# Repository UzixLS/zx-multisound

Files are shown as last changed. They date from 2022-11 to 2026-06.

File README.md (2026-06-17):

## ZX-MultiSound
Sound card for ZX Spectrum (NemoBus).

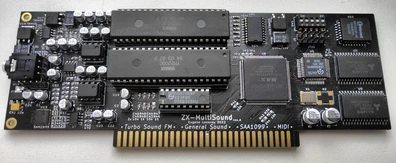
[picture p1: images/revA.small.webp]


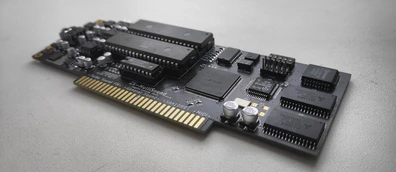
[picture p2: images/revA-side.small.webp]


### Tech specs
* TurboSound FM (2xYM2203)
* General Sound (16MHz, 1024Kb of RAM)
* SAA1099 (use port #FF/#1FF to access SAA chip, write #F7/#FF to #FFFD port to enable/disable SAA)
* SounDrive (ports #0F, #1F, #4F, #5F)
* MIDI synthesizer (controlled via YM(AY) chip - compatible with ZX Spectrum 128K / ZXUNO)
* Low profile PCB: 170x64mm
* 5V and 12V power required
* 4x 1-bit digital DACs for GS and SounDrive

### Changelog & current status
* Rev.A - first release. Please note the [errata](pcb/rev.A/ERRATA.txt);
* Rev.A1 - fixed known rev.A issues. Please note the [errata](pcb/rev.A1/ERRATA.txt).
* Rev.A2:
    * Fixed Z80 clocking - added buffer;
    * Fixed 3.5mm jack footprint swapped left-right channels;
    * Fixed misplaced R20 and R34 labels on silkscreen;
    * 74LVC1G125DB replaced by 74AHCT1G125DB;
    * C3,C5,C17,C18 slightly moved left;
    * Added ledge on edge connector;
    * Improved SAM2695 footprint for hand soldering.
Sound card has been tested only with ZX Evolution. You can use it with another computer at your own risk.

### Related projects
* Turbo Sound FM - [link](http://www.nedopc.com/TURBOSOUND/ts-fm.php)
* ZXM-SoundCard - [link](http://micklab.ru/My%20Soundcard/ZXMSoundCard.htm)
* ZXM-GeneralSound - [link](http://micklab.ru/My%20Soundcard/ZXMGeneralSound.htm)
* NeoGS - [link](http://www.nedopc.com/gs/ngs.php)

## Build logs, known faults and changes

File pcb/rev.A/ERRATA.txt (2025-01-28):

1. Missing MREQ signal. You should wire MREQ from edge connector to TP1
2. R2, R33 - 10K
3. R6, R12, R30, R31 - 47k

UPD. 2023-08-21:
4. R20 and R34 labels on silkscreen are misplaced
5. Incorrect 3.5mm jack footprint - left-right signals are swapped

UPD. 2025-01-28:
6. U21 should be 74AHCT1G125DB
7. Missing Z80 clock buffering. CPLD produce only up to 3.3V clock, while Z80 require 5V amplitude, and that may lead to unstable GS work. It's possible to use U14 for clock buffering.

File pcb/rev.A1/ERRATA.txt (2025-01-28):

1. R20 and R34 lables on silkscreen are misplaced
2. Incorrect 3.5mm jack footprint - left-right signals are swapped

UPD. 2025-01-28:
3. U21 should be 74AHCT1G125DB
4. Missing Z80 clock buffering. CPLD produce only up to 3.3V clock, while Z80 require 5V amplitude, and that may lead to unstable GS work. It's possible to use U14 for clock buffering.

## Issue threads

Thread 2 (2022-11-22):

Даешь больше дырок!

NEO-SPECTRUMAN, 2022-11-22:
Нету отверстий для прикручивания радиаторов к 2203

UzixLS, 2022-11-22:
Так надо водяную систему охлаждения использовать :)

NEO-SPECTRUMAN, 2022-11-22:
можно конечно преклеивать
но мне такая идея не нравитсо
а тотом придетсо отклеивать...

NEO-SPECTRUMAN, 2022-11-22:
кстате в данном случае может можно 2 штуки между 2203-ми
на термопасте хорошо ляжет на 2 опоры

UzixLS, 2022-11-22:
а зачем отклеивать если чип всё равно горячий?

NEO-SPECTRUMAN, 2022-11-22:
отклеивать от сгоревшего чтобы приклеить к новому :rofl:

NEO-SPECTRUMAN, 2022-11-22:
ну свидетели ложения чипов в вазочку на полочке не одобряют приклеивание чипов

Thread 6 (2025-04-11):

2203 busy latency and missed busy after reg select

NS-Clone, 2025-04-11:
вощем такие дела
записали на мультисаунде сигнал busy с 2203
и как оказалось
busy вообще не ОТСУТСТВУЕТ после выбора регистра
(собственно тоже самое и на 2612 и 3438)
когда он нужен

а busy мало того что одинаковый для всех регистров 90t (даже для SSG части)
так еще и после записи данных появляется с задержкой

график вероятности ловли сигнала busy после out (с),r
(не обращаем на зашумленность единицы на 28 мгц это изза недостаточного количества выборок и простоты визуализации графика)
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

и если на 3.5 Мгц все это проскакивается изза общей величины кода
то на 28МГц 10 тактов отсутствия busy это 80 такта z80...

и вот эта схема просто физически не работает уже даже на 14МГц
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

изза большого разброса частот проца
делать софтварную задержку не очень эффективно
хотя можно делать динамическую подстраиваемую под частоту проца

переключать на 3.5 МГц на время плеера
...успешно нельзя сейчас в недооси
ибо там какойто умник решил что частота должно щелкатсо раз в фрейм...

ну и конечно старые софты никто уже непофискит
да и новые еще будут выходить с игнором этой фичи...

как хардварное решение видитсо имитация сигнала busy средствами самой карты

в 2-х мануалах на более старшые OPN-ы
даютсо нужные времянки неготовности чипа

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

но это 6 канальные чипы на двойной частоте
и для нас эти времянки могут отличаются
(например фисировання длина busy на 2612 и 3438 192 такта против 90 у нас)
и нужные задержки видимо нужно подбирать методом научного тыка

так же на форуме сежистов упоминаетсо что якобы эти цифры похожи на правду
кроме регистра 0x28
которому надо 116 тактов
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

собственно мы немного тыкали софтварные задержки
и возможно этот 0x28 отвалилсо первым :)

NS-Clone, 2025-04-12:
рав данные того что выше с Koegon+Multisound
28, 14, 3.5 МГц (растянуто по коэфициенту турбы

в коегоне видимо 28МГц не 100%
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

еще подвезли записи с EVO+ZXM-Soundcard Extreme
14, 7, 3.5 МГц (растянуто по коэфициенту турбы

и тут мы видим вообще пропуски busy через такт в конце сигнала! на 14МГц
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

тк этот результат насторожил
добавил busy и на выбор регистра и на запись даты в унриал
и записал на частотах 28, 14, 7, 3.5 (в моем унриале турба щелкаетсо в отличииот ваших)

и там записался и busy после выбора регистра (которого нет на реале)
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

и busy после записи данных
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

обращаем внимание на отсутствие размытости краев

так что пока предполагаем что мой тест рабочий

UzixLS, 2025-04-19:
Я правильно понял что это "фича" самого 2203 и проявляется на всех картах с его использованием?

NS-Clone, 2025-04-19:
до
это фича походу всех opn-ов

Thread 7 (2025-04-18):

MIDI+Turbo

NS-Clone, 2025-04-18:
там много лгбт с этим биперным мидом в 100500 вариантах турбы

...а там жеш есть модифицированный ngs де стоит мп3декодер со встроенным мидом
можот и тут можно вынести (продублироваь) как то порты мида на сторону гс-а
(может даже сделать как то совместимо с тем нгс-ом)
и чтоб оно ужо само харваврно слало в sam2695 принимая по людски 1 байт
и отправляя последовательно уже само
может даже через порт Ay-ка (но самостоятельно без з80)
чтобы не менять плату

да и в саму прошивку гс-а можно было бы добавить режим пуляния данных в миду

UzixLS, 2025-04-19:
Вообще для миди в спектруме есть разные варианты подключения. Вот что, например, поддерживает Es.pectrum:
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
Вот только доки на всё это я хз где искать

NS-Clone, 2025-04-19:
> Вот только доки на всё это я хз где искать

да там в лохматые времена было много мидов...
вон у нас дажо скорпионовский мида был...

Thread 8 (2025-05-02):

Неработает GS на Коегоне

NS-Clone, 2025-05-02:
у трансмана из коробки незаводитсо ГС
(видимо на 3,5мгц тоже)
и судя по всему ужо 2-я карта подряд

тут я прицеплю цитату наверное от кое
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

хотя там у него еще проблема с ум-кой паралельна
может проблема и не в карте

UzixLS, 2025-05-03:
Какая ревизия платы? На A1 есть бага в GS части, на A2 поправлено: https://github.com/UzixLS/zx-multisound/blob/master/pcb/rev.A1/ERRATA.txt

Zorba2030, 2025-05-03:
ревизия А1. Сборка Tetroid'a. Но он проверяет перед отправкой на zx-evolution.
Какие варианты есть чтобы выяснить причину и починить, не окирпичив ее при этом?

UzixLS, 2025-05-03:
Тогда хз, гадать почему не работает можно очень долго, а Коегона (кстати, что это за клон? гугл не знает) у меня нету.

Zorba2030, 2025-05-03:
Это pentagon 2.666 le.
А что по поводу предположения, высказанного KoE о возможной причине несовместимости?

NS-Clone, 2025-05-03:
> а Коегона (кстати, что это за клон? гугл не знает) у меня нету.

в принципе коегона ниукого нету :rofl:
а про гуглу можно уже забывать...

UzixLS, 2025-05-03:
> А что по поводу предположения, высказанного KoE о возможной причине несовместимости?

Если под "неправильно формируется iorqge" имеется ввиду что в оригинальном ГС используются какие-то другие сигналы кроме m1 и шины адреса - то нет, в МС такого нет.

Closed 2025-05-04.

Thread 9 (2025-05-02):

Неправильный делитель на 2203 после сброса?

NS-Clone, 2025-05-02:
У трансмана на Коегоне (наверно 2.666ЛЕ) ВНЕЗАПНО перестал нормально играть AY
(типа играет на неправильной частоте)
хотя по началу он вроде играл
потом он ткнул другую такую карту
и там все тоже самое
(и на 3,5мгц вроде тоже не играет)

при этом судя по всему
после tsfm плееров которые инициализируют делитель
AY (SSG) потом играет нормально везде
(видимо фм часть тоже фурычит и так)

сам же 2203 по идеи должен сбрасывать делитель при сбросе

нет идей чего могло пойти не так?
типа "дребезга" сброса изза которого YM-ка неправильно сбрасываесто
или может пиковое потребление при старте большое а бп ужо не торт
этим можно было бы объяснить и нерабочесть ГС-а

UzixLS, 2025-05-03:
> сам же 2203 по идеи должен сбрасывать делитель при сбросе
Возможно, нет самого сигнала сброса либо он слишком короткий.

Zorba2030, 2025-05-03:
Всё-таки это оказался сигнал reset. При принудительной его активации всё начинает работать правильно.

NS-Clone, 2025-05-04:
до но интересно что оно жо работало с начала
тобешь это или "дребезг" усугубилсо
или блоку питания поплохело

Closed 2025-05-04.

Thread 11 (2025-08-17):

Clicks in TS/TSFM Mode

zxshock, 2025-08-17:
Noticed this during the demo loop for "Ball Quest" (https://files.scene.org/view/parties/2006/chaosconstructions06/game/ballques.zip)

If you look at the recordings there are noticeable clicks at 18.25 seconds, 20.5 seconds, 42.5 seconds and twice at 45.5 seconds (item pickups in first ingame demo). This also happens on Pentagon 1024SL 2.2
[ZX_Multisound-ZX_Evolution.mp3](https://github.com/user-attachments/files/21824429/ZX_Multisound-ZX_Evolution.mp3)

For comparision, this does not happen with a NedoPC TSFM (plugged into the AY socket, chips taken from my ZX Multisound to rule out defects)
[TSFM-ZX_Evolution.mp3](https://github.com/user-attachments/files/21824430/TSFM-ZX_Evolution.mp3)

Hardware:
ZX Multisound Revision A2, Firmware a696ecd (also happens with e952ec2)
TSFM (http://nedopc.com/TURBOSOUND/ts-fm.php, EPM7032 firmware from 29.05.2022)
ZX Evo Rev. C + dualConf (baseconf 21.09.2024 beta, AVR Boot 25.05.2019)

zxshock, 2025-08-20:
I'm confused (but then again I've never learned Verilog or Z80 debugging) ... and managed to get rid of the clicking in another way.

Doesn't seem to be related to bit3 (already wondered, as commenting out the whole SAA1099 section didn't help), but rather bit2?
Issue can also be fixed by commenting out lines 122 and 123, which of course disables FM. Still doesn't explain why checking for d3 to be 1 also fixed things - but at this point I'm just guessing

I've now made this change to the TSFM section, using SW1.5 for setting fm_ena and it seems to have fixed Ball Quest at the cost of disabling FM via the previously unused switch.

```
    else if (port_fffd && ioreq_wr && d[7:4] == 4'b1111 && fm_ena == 1'b1) begin
        ym_chip_sel <= d[0];
        ym_get_stat <= ~d[1];
        fm1_ena <= d[2]? 1'b0 : 1'bz;
        fm2_ena <= d[2]? 1'b0 : 1'bz;
    end
    else if (port_fffd && ioreq_wr && d[7:4] == 4'b1111 && fm_ena == 1'b0) begin
        ym_chip_sel <= d[0];
    end

```

Maybe this comes down to the different implementations of the FM enable in hardware? Open drain vs. 2 seperate signals (TSFM, TSFMPro, ZXM Soundcard)

UzixLS, 2025-08-21:
This should not be surprising. The clicks are not caused by the addressing itself, but by an unintentional change in the hardware configuration that is caused by the addressing.

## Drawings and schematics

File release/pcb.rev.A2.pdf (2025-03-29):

1 | 2 | 3 | 4 | 5 | 6 | 7 | 8 | 9 | 10

A

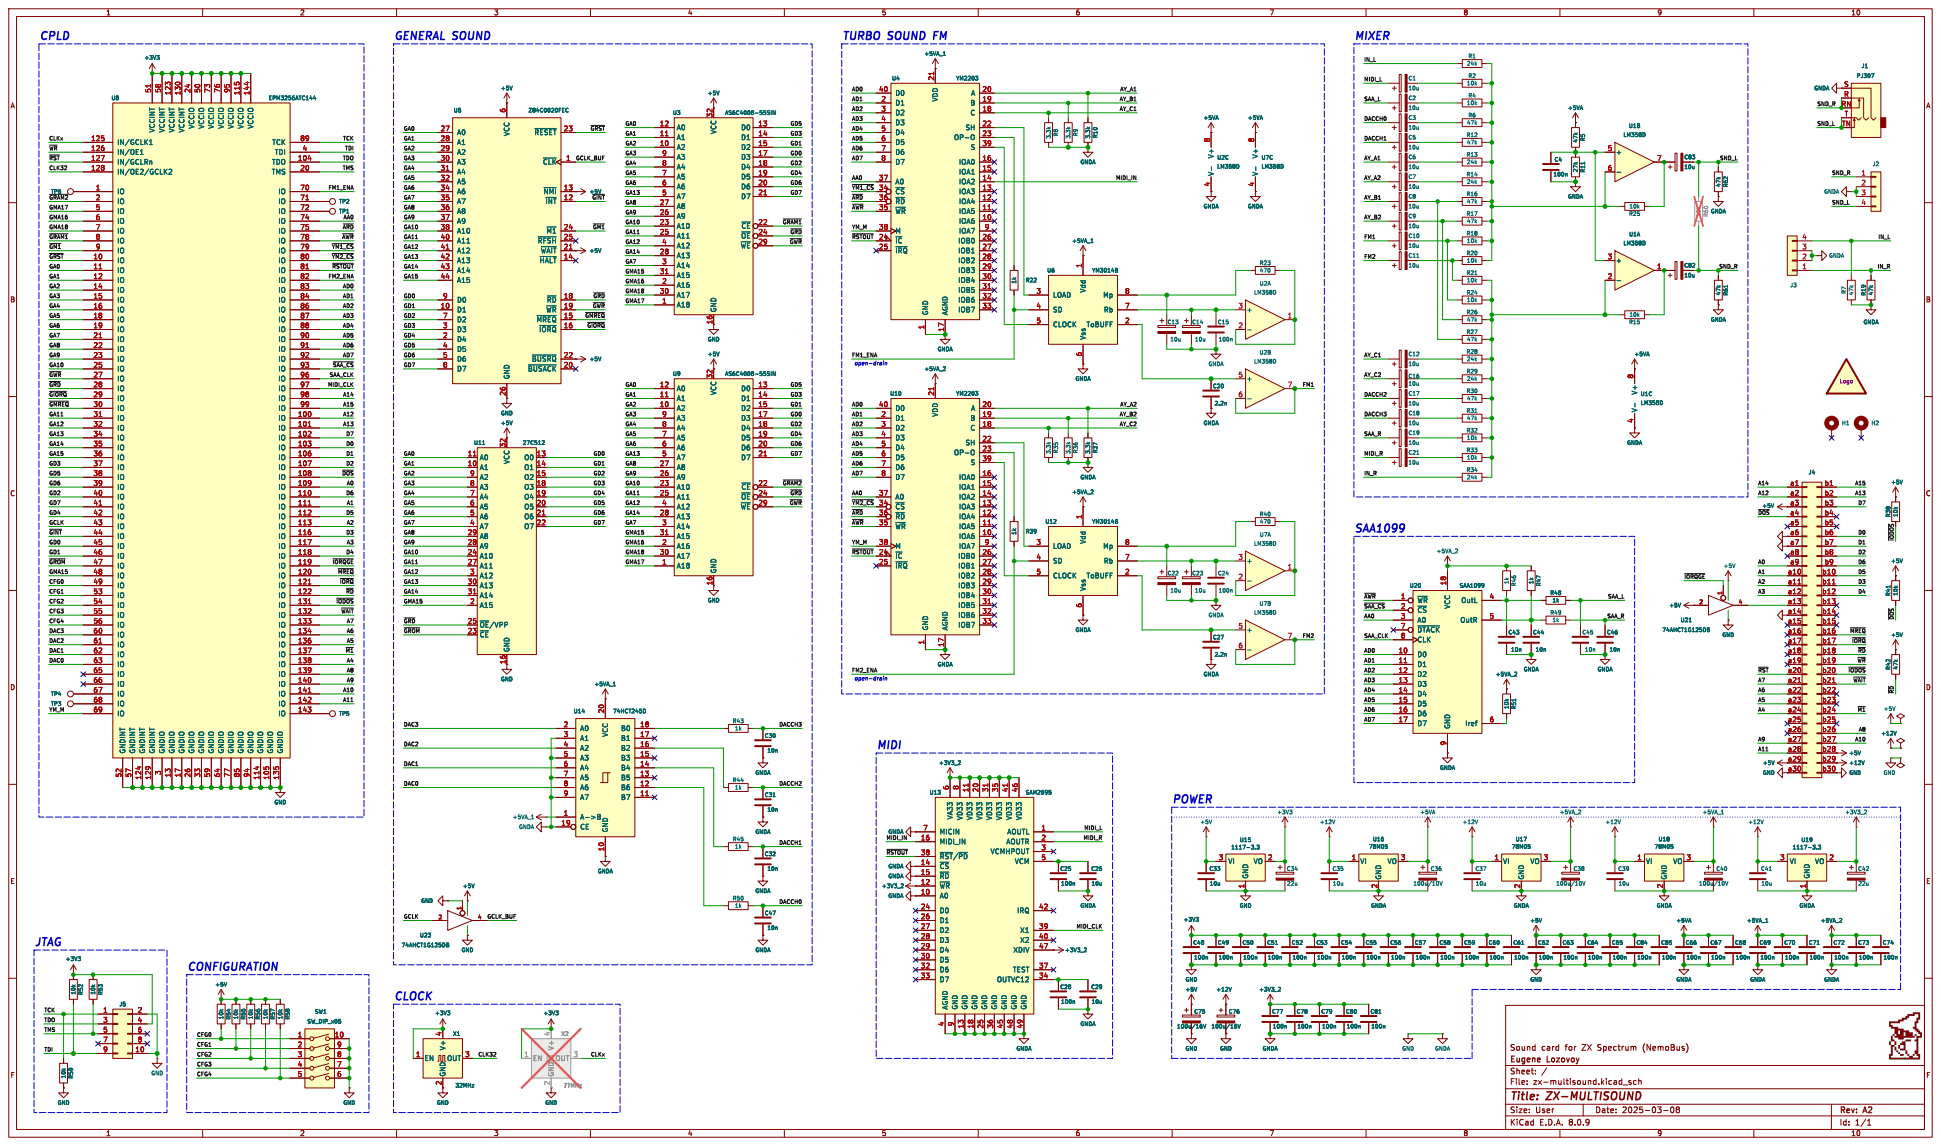
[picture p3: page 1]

9 GND 49 GNDA GNDA GNDA GNDA GNDA C28

Id: 1/1 Title: ZX-MULTISOUND

1 | 2 | 3 | 4 | 5 | 6

A

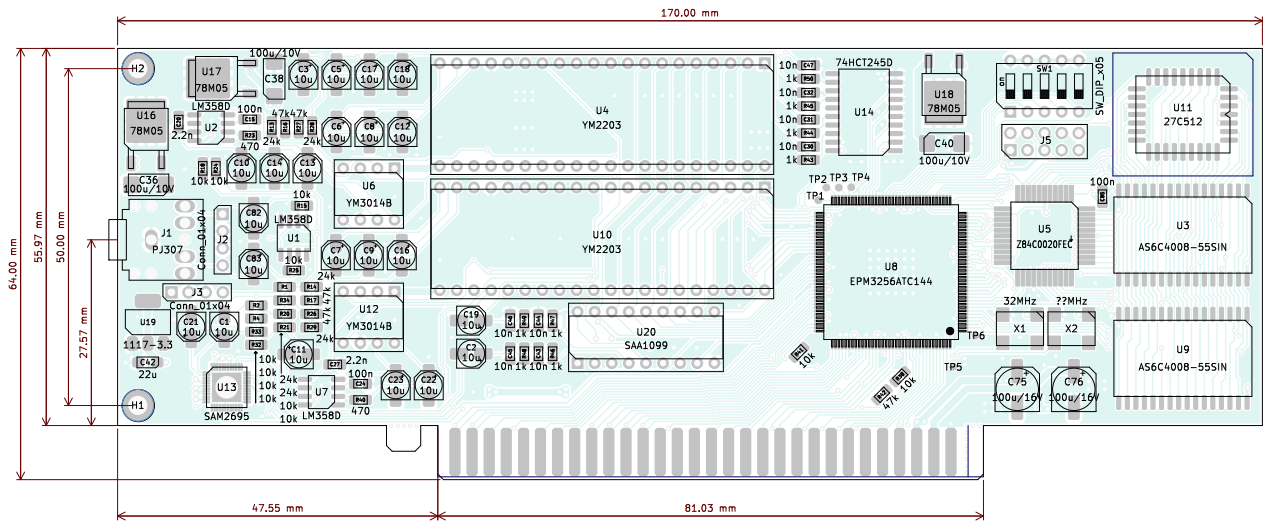
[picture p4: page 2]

Id: 1/1 Title: ZX-MULTISOUND

1 | 2 | 3 | 4 | 5 | 6

A

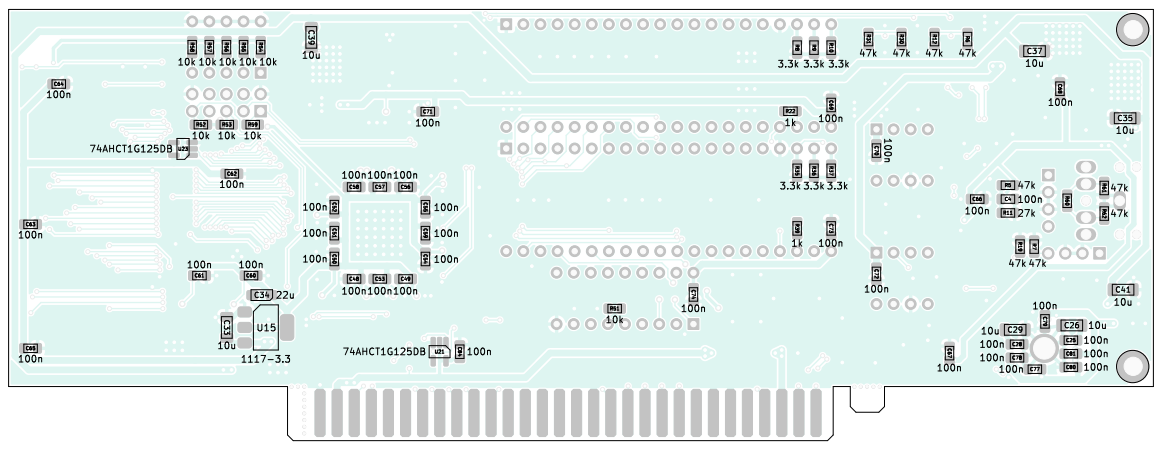
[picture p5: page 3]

Id: 1/1 Title: ZX-MULTISOUND

# Bill Of Materials

References | | | Value | Footprint | Qty
C1 C2 C3 C5 C6 C7 C8 C9 C10 C11 C12 C13 C14 C16 C17 C18 C19 C21 C22 C23 C82 C83 | 10u | Capacitor_SMD:CP_Elec_4x5.4 | 22
C4 C15 C24 C25 C28 C48 C49 C50 C51 C52 C53 C54 C55 C56 C57 C58 C59 C60 C61 C62 C63 C64 C65 C66 C67 C68 C69 C70 C71 C72 C73 C74 C77 C78 C79 C80 C81 C84 C85 | 100n | Capacitor_SMD:C_0805_2012Metric_Pad1.1 8x1.45mm_HandSolder | 39
C20 C27 | 2.2n | Capacitor_SMD:C_0805_2012Metric_Pad1.1 8x1.45mm_HandSolder | 2
C26 C29 C33 C35 C37 C39 C41 | 10u | Capacitor_SMD:C_1206_3216Metric_Pad1.3 3x1.80mm_HandSolder | 7
C30 C31 C32 C43 C44 C45 C46 C47 | 10n | Capacitor_SMD:C_0805_2012Metric_Pad1.1 8x1.45mm_HandSolder | 8
C34 C42 | 22u | Capacitor_Tantalum_SMD:CP_EIA-3216-18_ Kemet-A_Pad1.58x1.35mm_HandSolder | 2
C36 C38 C40 | 100u/10V | Capacitor_Tantalum_SMD:CP_EIA-6032-28_ Kemet-C_Pad2.25x2.35mm_HandSolder | 3
C75 C76 | 100u/16V | Capacitor_SMD:CP_Elec_6.3x7.7 | 2
J1 | PJ307 | my:PJ-307 | 1
J2 J3 | Conn_01x04 | Connector_PinHeader_2.54mm:PinHeader_1 x04_P2.54mm_Vertical | 2
J5 | Conn_02x05_Odd_Even | Connector_PinHeader_2.54mm:PinHeader_2 x05_P2.54mm_Vertical | 1
R1 R13 R14 R28 R29 R34 | 24k | Resistor_SMD:R_0805_2012Metric_Pad1.20 x1.40mm_HandSolder | 6
R2 R4 R15 R18 R20 R21 R24 R25 R32 R33 R38 R41 R51 R52 R53 R54 R55 R56 R57 R58 R59 | 10k | Resistor_SMD:R_0805_2012Metric_Pad1.20 x1.40mm_HandSolder | 21
R5 R6 R7 R12 R16 R17 R19 R26 R27 R30 R31 R42 R61 R62 | 47k | Resistor_SMD:R_0805_2012Metric_Pad1.20 x1.40mm_HandSolder | 14
R8 R9 R10 R35 R36 R37 | 3.3k | Resistor_SMD:R_0805_2012Metric_Pad1.20 x1.40mm_HandSolder | 6
R11 | 27k | Resistor_SMD:R_0805_2012Metric_Pad1.20 x1.40mm_HandSolder | 1
R22 R39 R43 R44 R45 R46 R47 R48 R49 R50 | 1k | Resistor_SMD:R_0805_2012Metric_Pad1.20 x1.40mm_HandSolder | 10
R23 R40 | 470 | Resistor_SMD:R_0805_2012Metric_Pad1.20 x1.40mm_HandSolder | 2
SW1 | SW_DIP_x05 | Button_Switch_THT:SW_DIP_SPSTx05_Slid e_6.7x14.26mm_W7.62mm_P2.54mm_LowP rofile | 1
U1 U2 U7 | LM358D | Package_SO:SOIC-8_3.9x4.9mm_P1.27mm | 3
U3 U9 | AS6C4008-55SIN | Package_SO:SSOP-32_11.305x20.495mm_ P1.27mm | 2
U4 U10 | YM2203 | Package_DIP:DIP-40_W15.24mm_Socket | 2
U5 | Z84C0020FEC | my:TQFP-44_14x14mm_P0.8mm | 1
U6 U12 | YM3014B | Package_DIP:DIP-8_W7.62mm_Socket | 2

# zx-multisound rev.A2 BOM page 1/2

U8 | EPM3256ATC144 | PCM_Package_QFP_AKL:TQFP-144_20x20 mm_P0.5mm | 1
U11 | 27C512 | my:PLCC-32_11.4x14.0mm_P1.27mm-longp ads | 1
U13 | SAM2695 | my:QFN-48-1EP_6x6mm_P0.4mm_EP4.2x4. 2mm | 1
U14 | 74HCT245D | Package_SO:SOIC-20W_7.5x12.8mm_P1.27 mm | 1
U15 U19 | 1117-3.3 | Package_TO_SOT_SMD:SOT-223-3_TabPin 2 | 2
U16 U17 U18 | 78M05 | Package_TO_SOT_SMD:TO-252-2 | 3
U20 | SAA1099 | Package_DIP:DIP-18_W7.62mm_Socket | 1
U21 U23 | 74AHCT1G125DB | Package_TO_SOT_SMD:SOT-23-5_HandSo ldering | 2
X1 | 32MHz | my:Oscillator_SMD_7050_7.0x5.0mm | 1

# zx-multisound rev.A2 BOM page 2/2

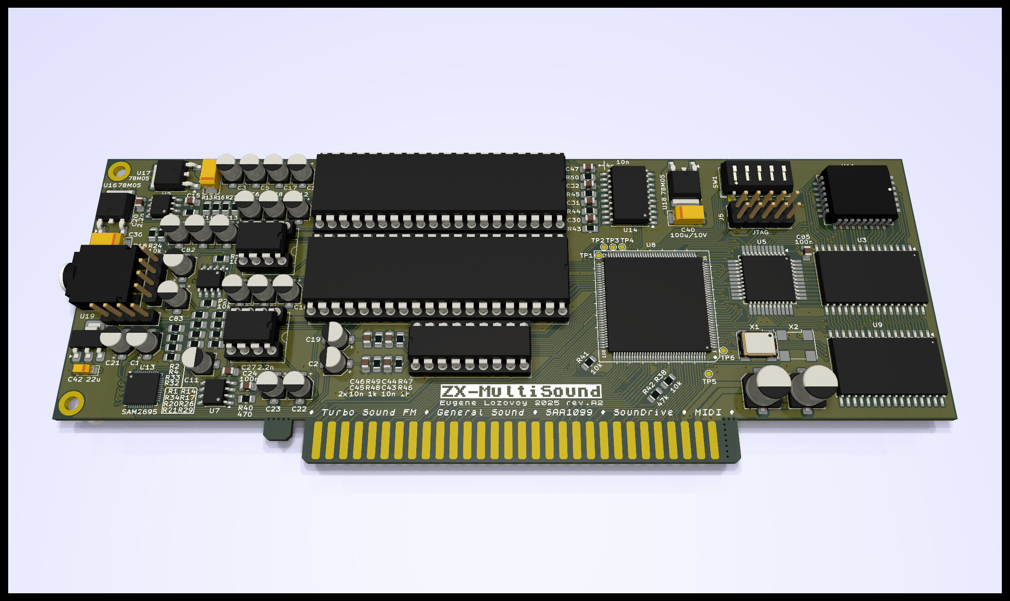
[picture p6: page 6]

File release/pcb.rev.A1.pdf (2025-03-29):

1 | 2 | 3 | 4 | 5 | 6 | 7 | 8 | 9 | 10

A

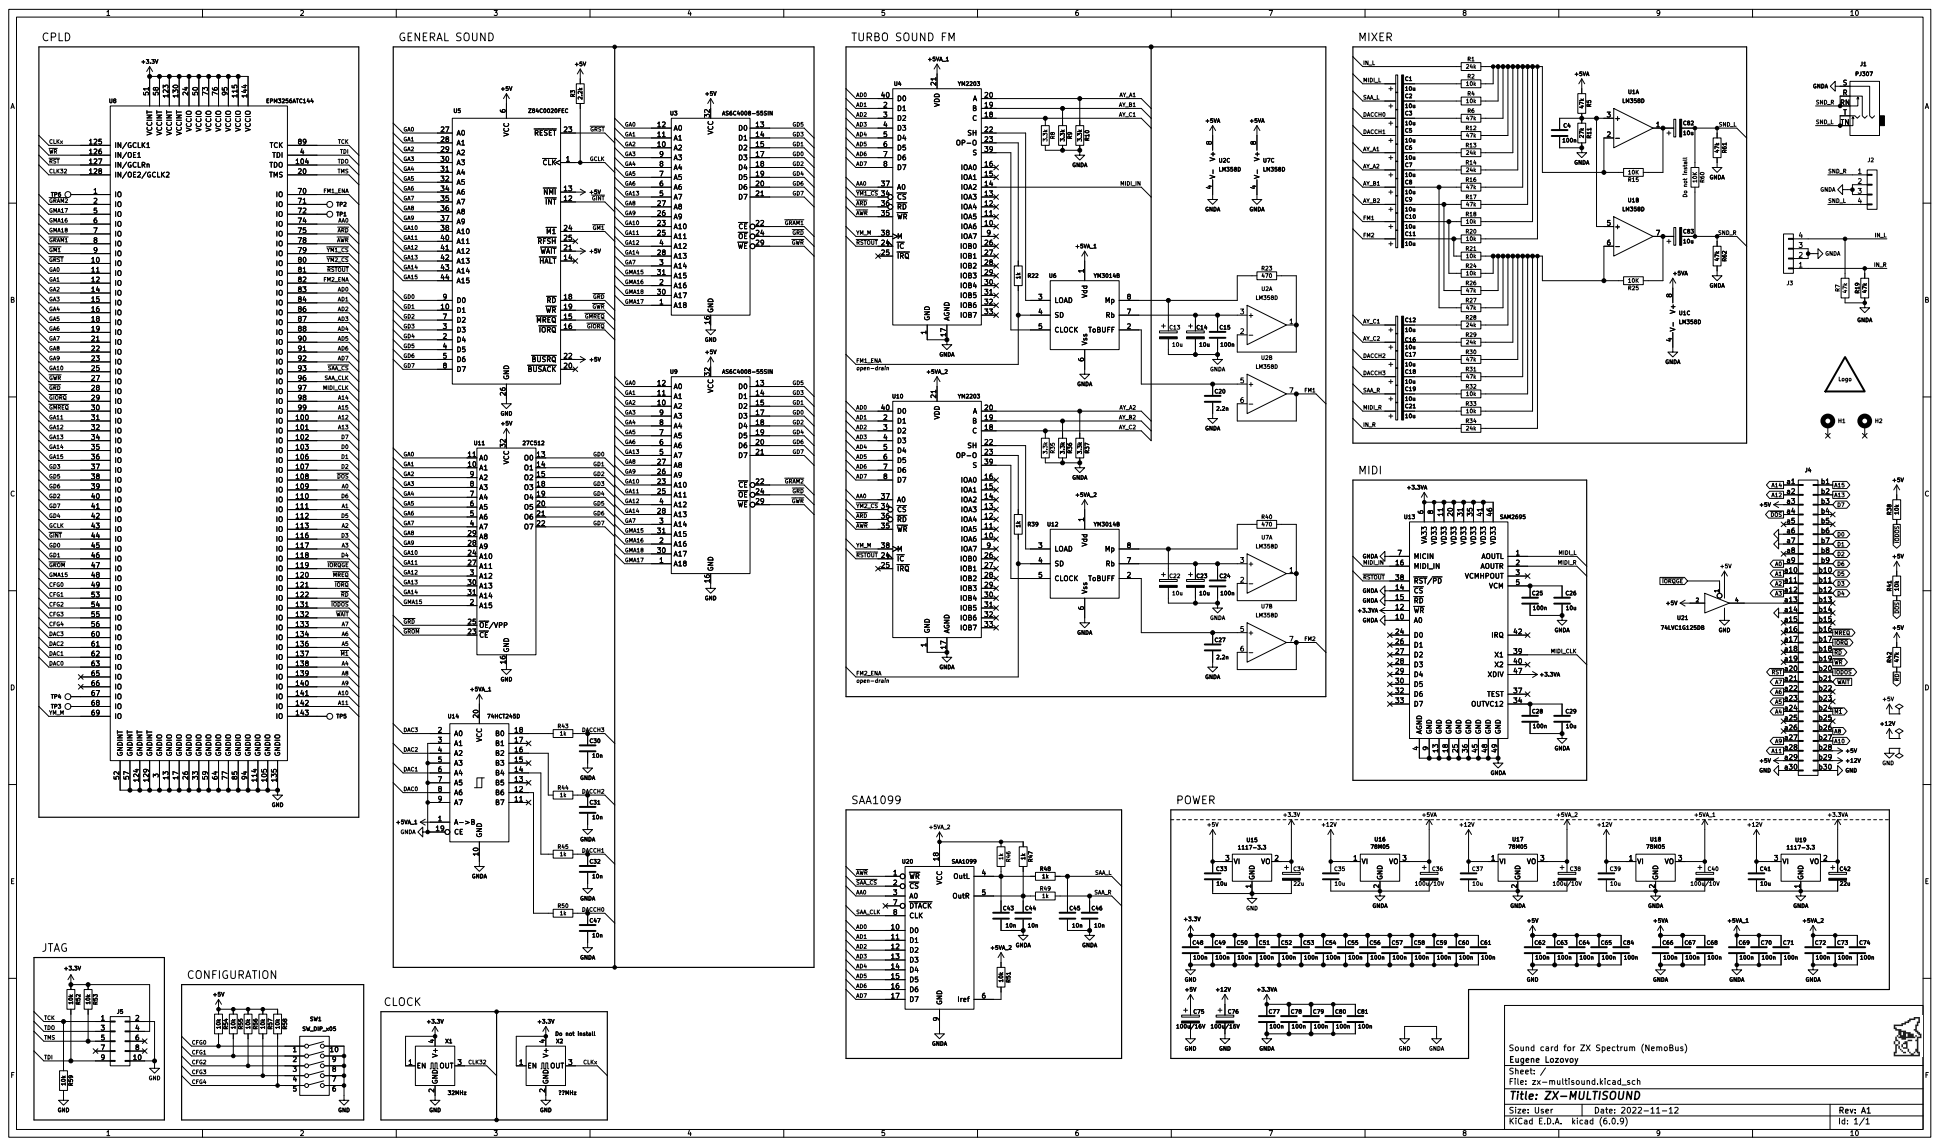
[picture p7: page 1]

Sound card for ZX Spectrum (NemoBus)
Eugene Lozovoy
Sheet: /

1 | 2 | 3 | 4 | 5 | 6

A

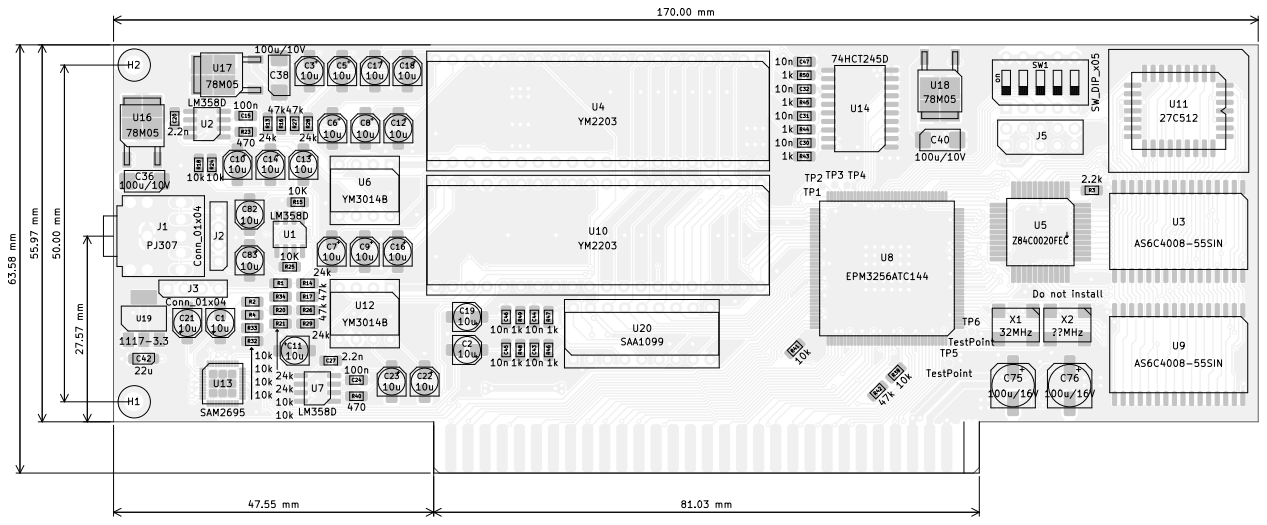
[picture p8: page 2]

1 | 2 | 3 | 4 | 5 | 6

A

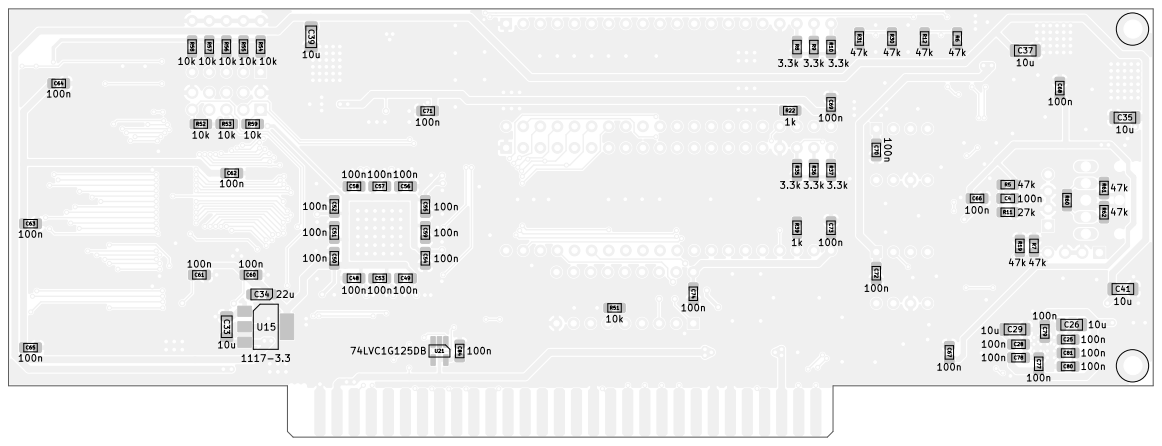
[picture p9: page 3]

Designator | Package | Value | Quantity
C1, C2, C3, C5, C6, C7, C8, C9, C10, C11, C12, C13, C14, C16, C17, C18, C19, C21, C22, C23, C82, C83 | CP_Elec_4x5.4 | 10u | 22
C4, C15, C24, C25, C28, C48, C49, C50, C51, C52, C53, C54, C55, C56, C57, C58, C59, C60, C61, C62, C63, C64, C65, C66, C67, C68, C69, C70, C71, C72, C73, C74, C77, C78, C79, C80, C81, C84 | C_0805_2012Metric_Pad1.18x1.45mm_HandSolder | 100n | 38
C20, C27 | C_0805_2012Metric_Pad1.18x1.45mm_HandSolder | 2.2n | 2
C26, C29, C33, C35, C37, C39, C41 | C_1206_3216Metric_Pad1.33x1.80mm_HandSolder | 10u | 7
C30, C31, C32, C43, C44, C45, C46, C47 | C_0805_2012Metric_Pad1.18x1.45mm_HandSolder | 10n | 8
C34, C42 | CP_EIA-3216-18_Kemet-A_Pad1.58x1.35mm_HandSolder | 22u | 2
C36, C38, C40 | CP_EIA-6032-28_Kemet-C_Pad2.25x2.35mm_HandSolder | 100u/10V | 3
C75, C76 | CP_Elec_6.3x7.7 | 100u/16V | 2
J1 | SWITCHCRAFT_35RAPC4BHN2 | PJ307 | 1
J2, J3 | PinHeader_1x04_P2.54mm_Vertical | Conn_01x04 | 2
J5 | PinHeader_2x05_P2.54mm_Vertical | Conn_02x05_Odd_E ven | 1
R1, R13, R14, R28, R29, R34 | R_0805_2012Metric_Pad1.20x1.40mm_HandSolder | 24k | 6
R2, R4, R18, R20, R21, R24, R32, R33, R38, R41, R51, R52, R53, R54, R55, R56, R57, R58, R59 | R_0805_2012Metric_Pad1.20x1.40mm_HandSolder | 10k | 19
R3 | R_0805_2012Metric_Pad1.20x1.40mm_HandSolder | 2.2k | 1
R5, R6, R7, R12, R16, R17, R19, R26, R27, R30, R31, R42, R61, R62 | R_0805_2012Metric_Pad1.20x1.40mm_HandSolder | 47k | 14
R8, R9, R10, R35, R36, R37 | R_0805_2012Metric_Pad1.20x1.40mm_HandSolder | 3.3k | 6
R11 | R_0805_2012Metric_Pad1.20x1.40mm_HandSolder | 27k | 1
R15, R25 | R_0805_2012Metric_Pad1.20x1.40mm_HandSolder | 10K | 2
R22, R39, R43, R44, R45, R46, R47, R48, R49, R50 | R_0805_2012Metric_Pad1.20x1.40mm_HandSolder | 1k | 10
R23, R40 | R_0805_2012Metric_Pad1.20x1.40mm_HandSolder | 470 | 2
SW1 | SW_DIP_SPSTx05_Slide_6.7x14.26mm_W7.62mm_P2.54mm _LowProfile | SW_DIP_x05 | 1
U1, U2, U7 | SOIC-8_3.9x4.9mm_P1.27mm | LM358D | 3
U3, U9 | SSOP-32_11.305x20.495mm_P1.27mm | AS6C4008-55SIN | 2
U4, U10 | DIP-40_W15.24mm_Socket | YM2203 | 2
U5 | TQFP-44_14x14mm_P0.8mm | Z84C0020FEC | 1
U6, U12 | DIP-8_W7.62mm_Socket | YM3014B | 2
U8 | TQFP-144_20x20mm_P0.5mm | EPM3256ATC144 | 1
U11 | PLCC-32_11.4x14.0mm_P1.27mm-longpads | 27C512 | 1
U13 | QFN-48-1EP_6x6mm_P0.4mm_EP4.2x4.2mm | SAM2695 | 1
U14 | SOIC-20W_7.5x12.8mm_P1.27mm | 74HCT245D | 1
U15, U19 | SOT-223-3_TabPin2 | 1117-3.3 | 2
U16, U17, U18 | TO-252-2 | 78M05 | 3
U20 | DIP-18_W7.62mm_Socket | SAA1099 | 1
U21 | SOT-23-5_HandSoldering | 74LVC1G125DB | 1
X1 | my:Oscillator_SMD_7050_7.0x5.0mm | 32MHz | 1

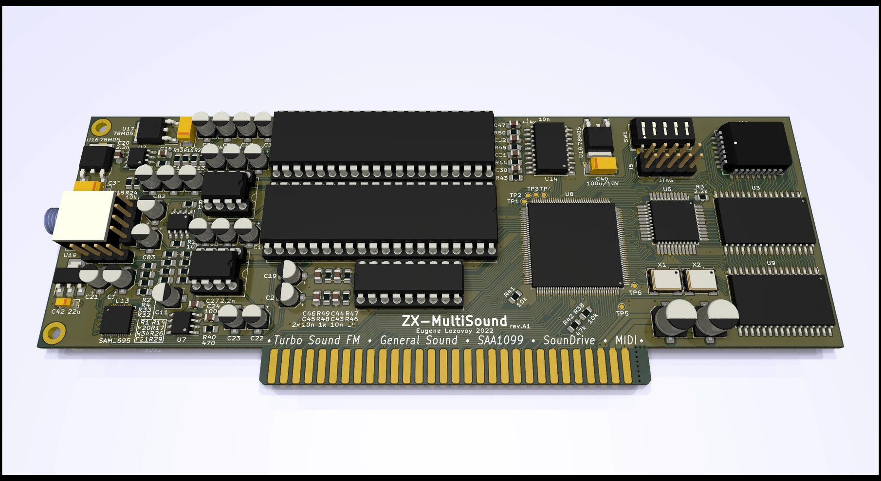
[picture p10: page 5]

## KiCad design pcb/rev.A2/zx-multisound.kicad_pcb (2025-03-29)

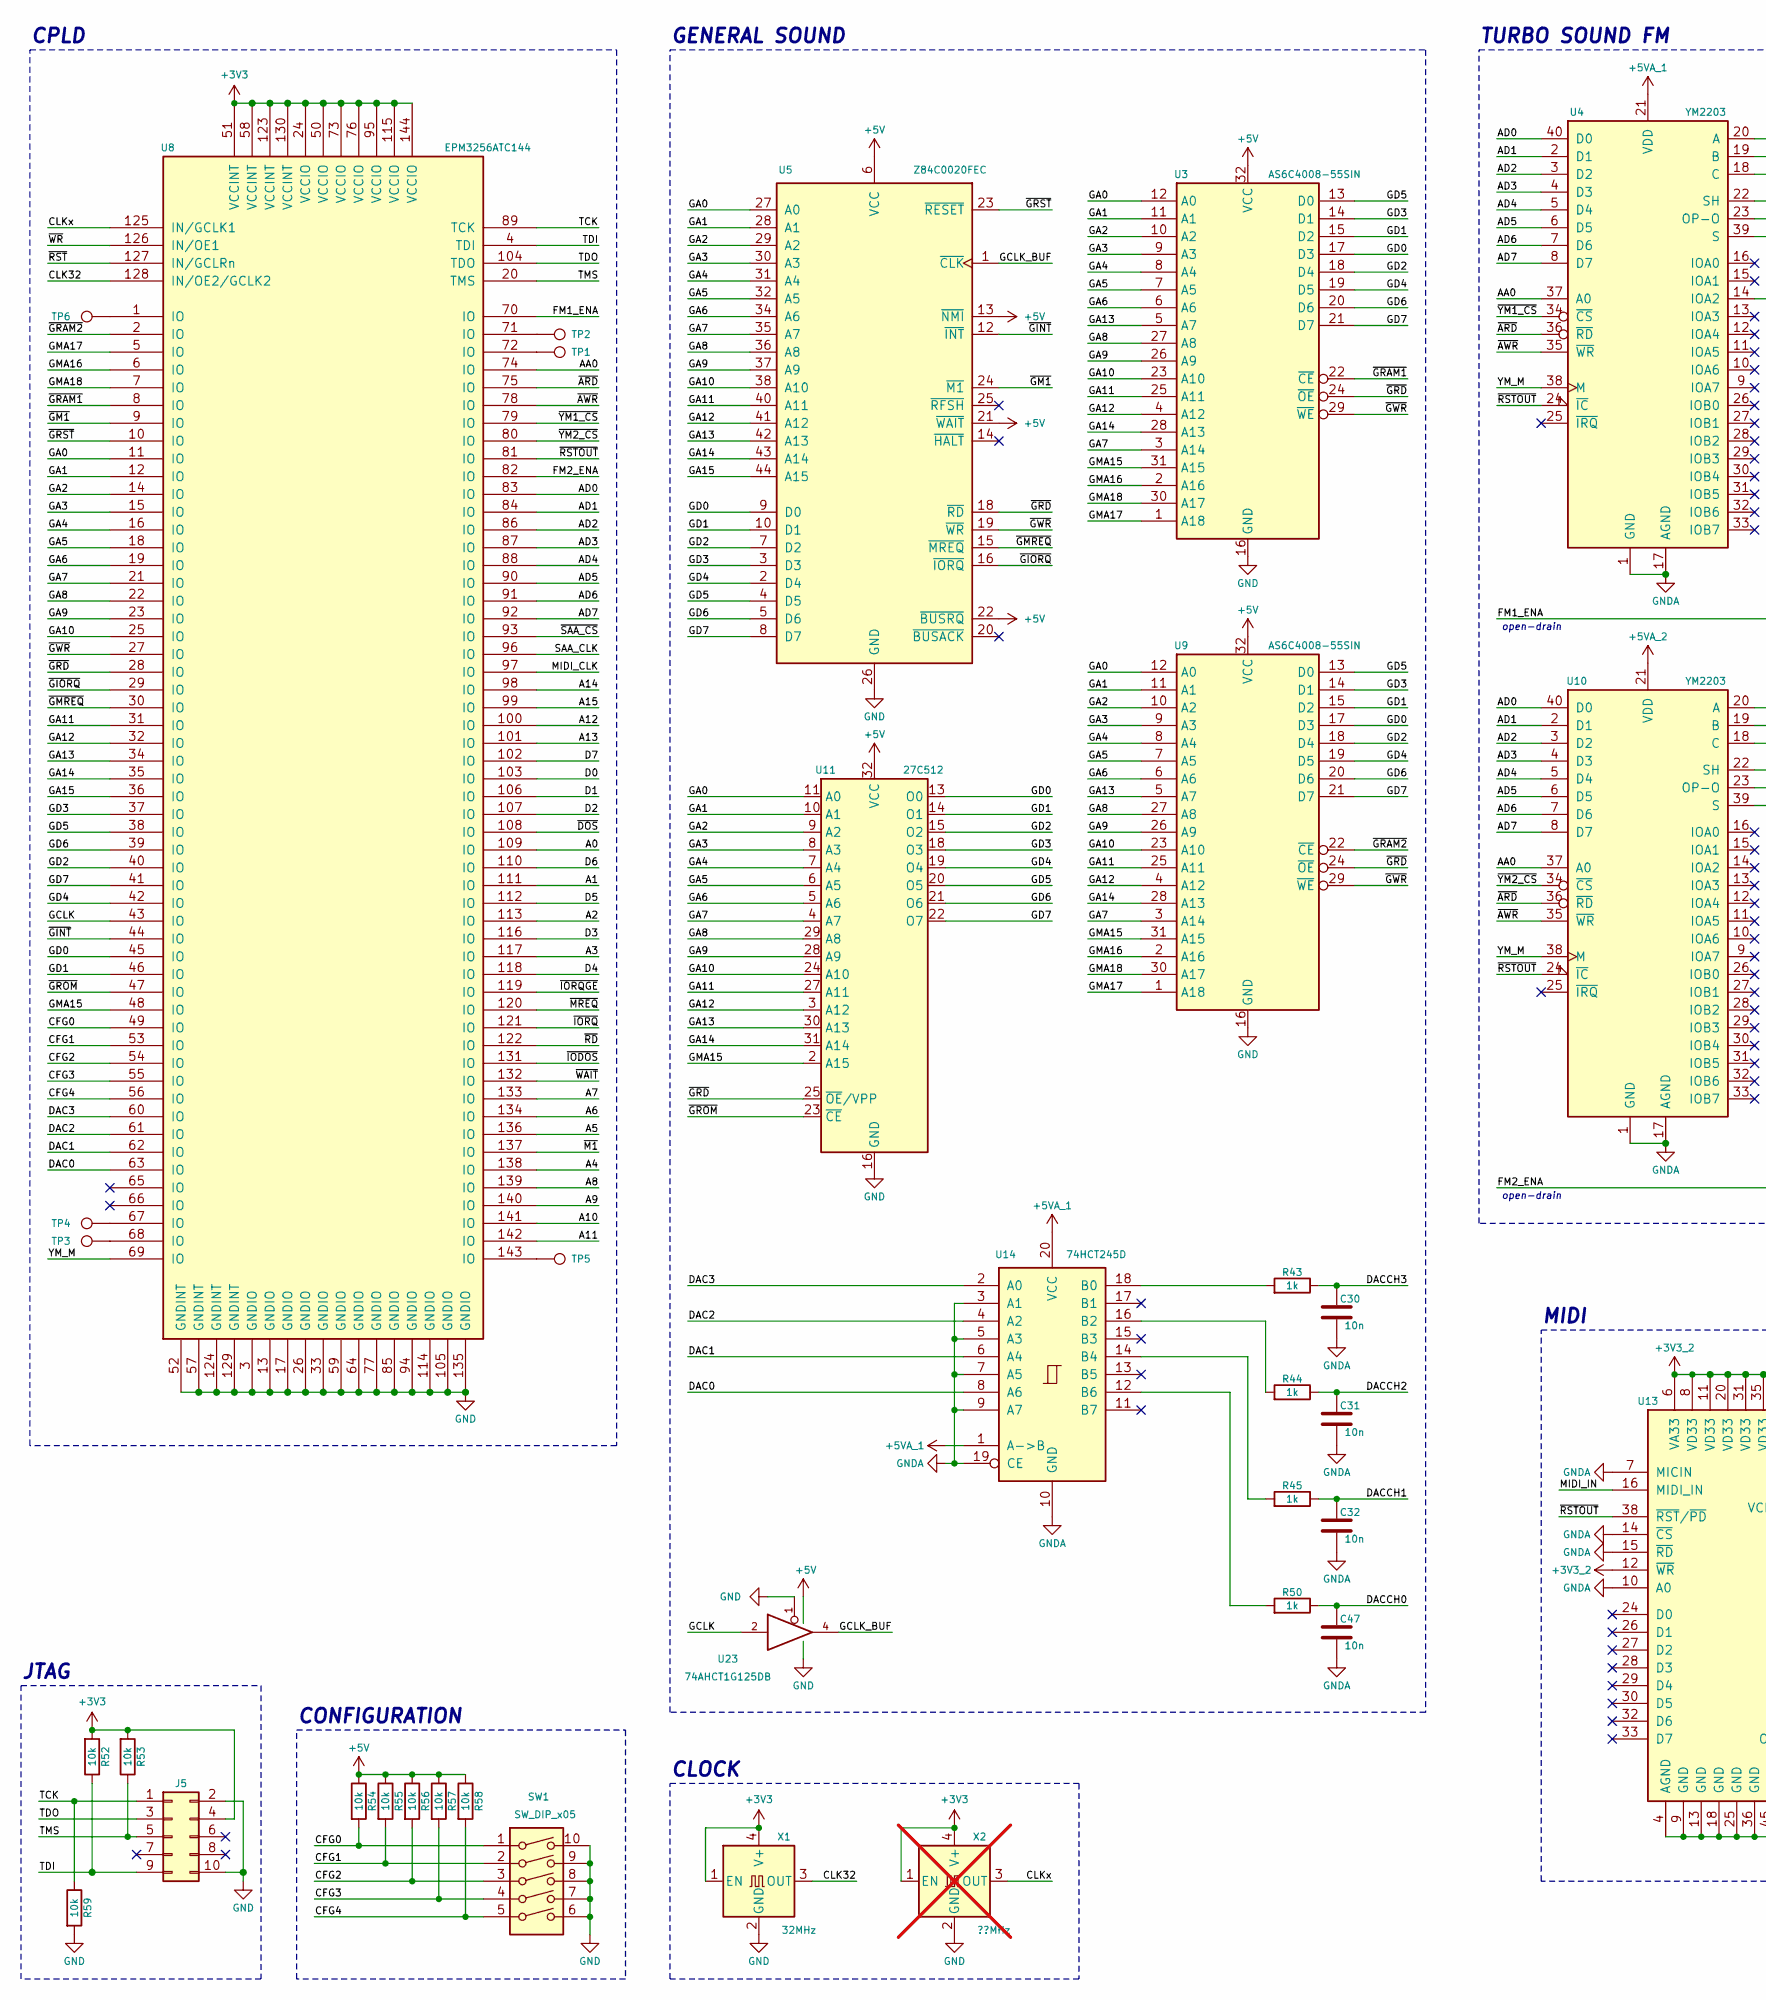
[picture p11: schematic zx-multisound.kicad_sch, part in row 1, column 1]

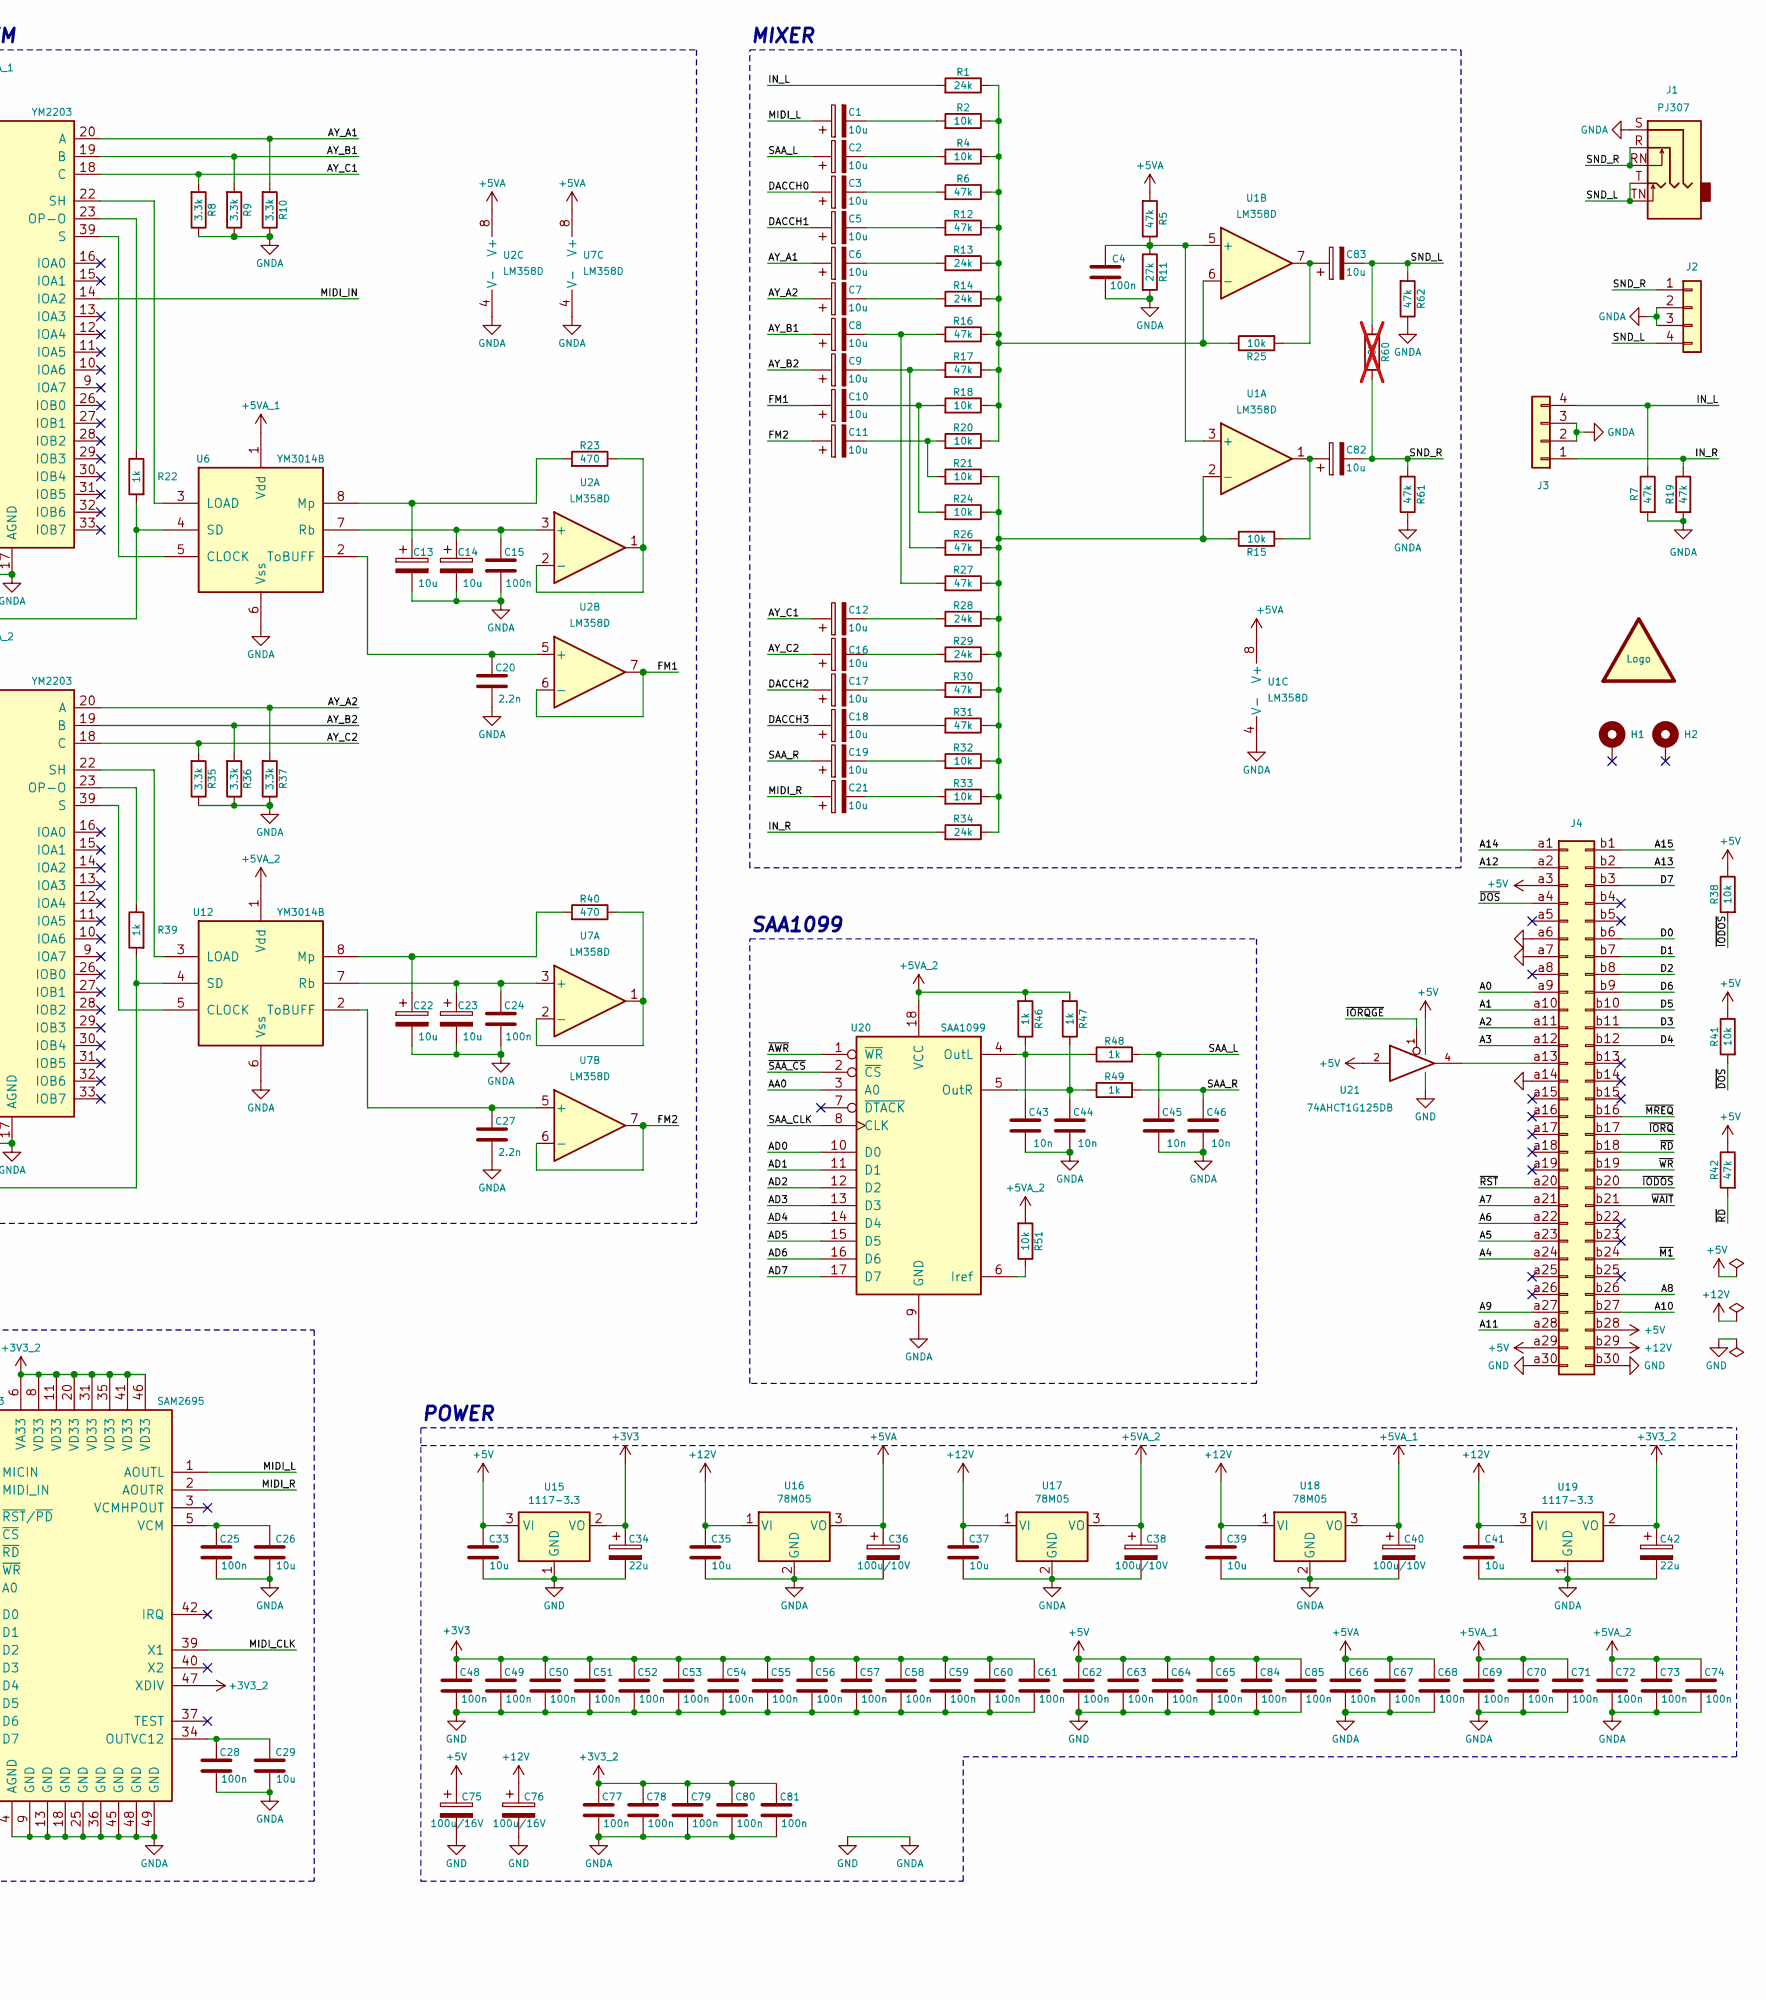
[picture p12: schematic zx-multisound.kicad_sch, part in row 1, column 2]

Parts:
C1, C2, C3, C5, C6, C7, C8, C9, C10, C11, C12, C13, C14, C16, C17, C18, C19, C21, C22, C23, C82, C83: 10u; CP_Elec_4x5.4
C4, C15, C24, C25, C28, C48, C49, C50, C51, C52, C53, C54, C55, C56, C57, C58, C59, C60, C61, C62, C63, C64, C65, C66, C67, C68, C69, C70, C71, C72, C73, C74, C77, C78, C79, C80, C81, C84, C85: 100n; C_0805_2012Metric_Pad1.18x1.45mm_HandSolder
C20, C27: 2.2n; C_0805_2012Metric_Pad1.18x1.45mm_HandSolder
C26, C29, C33, C35, C37, C39, C41: 10u; C_1206_3216Metric_Pad1.33x1.80mm_HandSolder
C30, C31, C32, C43, C44, C45, C46, C47: 10n; C_0805_2012Metric_Pad1.18x1.45mm_HandSolder
C34, C42: 22u; CP_EIA-3216-18_Kemet-A_Pad1.58x1.35mm_HandSolder
C36, C38, C40: 100u/10V; CP_EIA-6032-28_Kemet-C_Pad2.25x2.35mm_HandSolder
C75, C76: 100u/16V; CP_Elec_6.3x7.7
H1, H2: MountingHole_Pad; MountingHole_2.7mm_M2.5_DIN965_Pad
J1: PJ307; PJ-307
J2, J3: Conn_01x04; PinHeader_1x04_P2.54mm_Vertical
J4: Conn_02x30_Row_Letter_First; ZX_NEMO_60_EDGE
J5: Conn_02x05_Odd_Even; PinHeader_2x05_P2.54mm_Vertical
LOGO1: graphic; black-mage-12.5x8.6
R1, R13, R14, R28, R29, R34: 24k; R_0805_2012Metric_Pad1.20x1.40mm_HandSolder
R2, R4, R15, R18, R20, R21, R24, R25, R32, R33, R38, R41, R51, R52, R53, R54, R55, R56, R57, R58, R59: 10k; R_0805_2012Metric_Pad1.20x1.40mm_HandSolder
R5, R6, R7, R12, R16, R17, R19, R26, R27, R30, R31, R42, R61, R62: 47k; R_0805_2012Metric_Pad1.20x1.40mm_HandSolder
R8, R9, R10, R35, R36, R37: 3.3k; R_0805_2012Metric_Pad1.20x1.40mm_HandSolder
R11: 27k; R_0805_2012Metric_Pad1.20x1.40mm_HandSolder
R22, R39, R43, R44, R45, R46, R47, R48, R49, R50: 1k; R_0805_2012Metric_Pad1.20x1.40mm_HandSolder
R23, R40: 470; R_0805_2012Metric_Pad1.20x1.40mm_HandSolder
R60: 10K; R_0805_2012Metric_Pad1.20x1.40mm_HandSolder; not fitted
SW1: SW_DIP_x05; SW_DIP_SPSTx05_Slide_6.7x14.26mm_W7.62mm_P2.54mm_LowProfile
TP1, TP2, TP3, TP4, TP5, TP6: TestPoint; TestPoint_Pad_D1.0mm
U1, U2, U7: LM358D; SOIC-8_3.9x4.9mm_P1.27mm
U3, U9: AS6C4008-55SIN; SSOP-32_11.305x20.495mm_P1.27mm
U4, U10: YM2203; DIP-40_W15.24mm_Socket
U5: Z84C0020FEC; TQFP-44_14x14mm_P0.8mm
U6, U12: YM3014B; DIP-8_W7.62mm_Socket
U8: EPM3256ATC144; TQFP-144_20x20mm_P0.5mm
U11: 27C512; PLCC-32_11.4x14.0mm_P1.27mm-longpads
U13: SAM2695; QFN-48-1EP_6x6mm_P0.4mm_EP4.2x4.2mm
U14: 74HCT245D; SOIC-20W_7.5x12.8mm_P1.27mm
U15, U19: 1117-3.3; SOT-223-3_TabPin2
U16, U17, U18: 78M05; TO-252-2
U20: SAA1099; DIP-18_W7.62mm_Socket
U21, U23: 74AHCT1G125DB; SOT-23-5_HandSoldering
X1: 32MHz; Oscillator_SMD_7050_7.0x5.0mm
X2: ??MHz; Oscillator_SMD_7050_7.0x5.0mm; not fitted

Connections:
+3V3: C34.1, C48.1, C49.1, C50.1, C51.1, C52.1, C53.1, C54.1, C55.1, C56.1, C57.1, C58.1, C59.1, C60.2, C61.2, J5.4, R52.2, R53.2, U8.24 (VCCIO), U8.50 (VCCIO), U8.51 (VCCINT), U8.58 (VCCINT), U8.73 (VCCIO), U8.76 (VCCIO), U8.95 (VCCIO), U8.115 (VCCIO), U8.123 (VCCINT), U8.130 (VCCINT), U8.144 (VCCIO), U15.2 (VO), X1.1 (EN), X1.4 (V+), X2.1 (EN), X2.4 (V+)
+3V3_2: C42.1, C77.1, C78.1, C79.1, C80.1, C81.1, U13.6 (VA33), U13.8 (VD33), U13.11 (VD33), U13.12 (~WR), U13.20 (VD33), U13.31 (VD33), U13.35 (VD33), U13.41 (VD33), U13.46 (VD33), U13.47 (XDIV), U19.2 (VO)
+5V: C33.1, C62.2, C63.2, C64.2, C65.2, C75.1, C84.2, C85.2, J4.a3, J4.a29, J4.b28, R38.1, R41.1, R42.1, R54.1, R55.1, R56.1, R57.1, R58.1, U3.32 (VCC), U5.6 (VCC), U5.13 (~NMI), U5.21 (~WAIT), U5.22 (~BUSRQ), U9.32 (VCC), U11.32 (VCC), U15.3 (VI), U21.2, U21.5 (VCC), U23.5 (VCC)
+5VA: C36.1, C66.2, C67.2, C68.2, R5.2, U1.8 (V+), U2.8 (V+), U7.8 (V+), U16.3 (VO)
+5VA_1: C40.1, C69.2, C70.2, C71.2, U4.21 (VDD), U6.1 (Vdd), U14.1 (A->B), U14.20 (VCC), U18.3 (VO)
+5VA_2: C38.1, C72.2, C73.2, C74.2, R46.2, R47.2, R51.2, U10.21 (VDD), U12.1 (Vdd), U17.3 (VO), U20.18 (VCC)
+12V: C35.1, C37.1, C39.1, C41.1, C76.1, J4.b29, U16.1 (VI), U17.1 (VI), U18.1 (VI), U19.3 (VI)
/A0: J4.a9, U8.109 (IO)
/A1: J4.a10, U8.111 (IO)
/A2: J4.a11, U8.113 (IO)
/A3: J4.a12, U8.117 (IO)
/A4: J4.a24, U8.138 (IO)
/A5: J4.a23, U8.136 (IO)
/A6: J4.a22, U8.134 (IO)
/A7: J4.a21, U8.133 (IO)
/A8: J4.b26, U8.139 (IO)
/A9: J4.a27, U8.140 (IO)
/A10: J4.b27, U8.141 (IO)
/A11: J4.a28, U8.142 (IO)
/A12: J4.a2, U8.100 (IO)
/A13: J4.b2, U8.101 (IO)
/A14: J4.a1, U8.98 (IO)
/A15: J4.b1, U8.99 (IO)
/AA0: U4.37 (A0), U8.74 (IO), U10.37 (A0), U20.3 (A0)
/AD0: U4.40 (D0), U8.83 (IO), U10.40 (D0), U20.10 (D0)
/AD1: U4.2 (D1), U8.84 (IO), U10.2 (D1), U20.11 (D1)
/AD2: U4.3 (D2), U8.86 (IO), U10.3 (D2), U20.12 (D2)
/AD3: U4.4 (D3), U8.87 (IO), U10.4 (D3), U20.13 (D3)
/AD4: U4.5 (D4), U8.88 (IO), U10.5 (D4), U20.14 (D4)
/AD5: U4.6 (D5), U8.90 (IO), U10.6 (D5), U20.15 (D5)
/AD6: U4.7 (D6), U8.91 (IO), U10.7 (D6), U20.16 (D6)
/AD7: U4.8 (D7), U8.92 (IO), U10.8 (D7), U20.17 (D7)
/AY_A1: C6.1, R10.2, U4.20 (A)
/AY_A2: C7.1, R37.2, U10.20 (A)
/AY_B1: C8.1, R9.2, U4.19 (B)
/AY_B2: C9.1, R36.2, U10.19 (B)
/AY_C1: C12.1, R8.2, U4.18 (C)
/AY_C2: C16.1, R35.2, U10.18 (C)
/CFG0: R54.2, SW1.1, U8.49 (IO)
/CFG1: R55.2, SW1.2, U8.53 (IO)
/CFG2: R56.2, SW1.3, U8.54 (IO)
/CFG3: R57.2, SW1.4, U8.55 (IO)
/CFG4: R58.2, SW1.5, U8.56 (IO)
/CLK32: U8.128 (IN/OE2/GCLK2), X1.3 (OUT)
/CLKx: U8.125 (IN/GCLK1), X2.3 (OUT)
/D0: J4.b6, U8.103 (IO)
/D1: J4.b7, U8.106 (IO)
/D2: J4.b8, U8.107 (IO)
/D3: J4.b11, U8.116 (IO)
/D4: J4.b12, U8.118 (IO)
/D5: J4.b10, U8.112 (IO)
/D6: J4.b9, U8.110 (IO)
/D7: J4.b3, U8.102 (IO)
/DAC0: U8.63 (IO), U14.8 (A6)
/DAC1: U8.62 (IO), U14.6 (A4)
/DAC2: U8.61 (IO), U14.4 (A2)
/DAC3: U8.60 (IO), U14.2 (A0)
/DACCH0: C3.1, C47.1, R50.1
/DACCH1: C5.1, C32.1, R45.1
/DACCH2: C17.1, C31.1, R44.1
/DACCH3: C18.1, C30.1, R43.1
/FM1: C10.1, U2.6 (-), U2.7
/FM1_ENA: R22.2, U6.4 (SD), U8.70 (IO)
/FM2: C11.1, U7.6 (-), U7.7
/FM2_ENA: R39.2, U8.82 (IO), U12.4 (SD)
/GA0: U3.12 (A0), U5.27 (A0), U8.11 (IO), U9.12 (A0), U11.11 (A0)
/GA1: U3.11 (A1), U5.28 (A1), U8.12 (IO), U9.11 (A1), U11.10 (A1)
/GA2: U3.10 (A2), U5.29 (A2), U8.14 (IO), U9.10 (A2), U11.9 (A2)
/GA3: U3.9 (A3), U5.30 (A3), U8.15 (IO), U9.9 (A3), U11.8 (A3)
/GA4: U3.8 (A4), U5.31 (A4), U8.16 (IO), U9.8 (A4), U11.7 (A4)
/GA5: U3.7 (A5), U5.32 (A5), U8.18 (IO), U9.7 (A5), U11.6 (A5)
/GA6: U3.6 (A6), U5.34 (A6), U8.19 (IO), U9.6 (A6), U11.5 (A6)
/GA7: U3.3 (A14), U5.35 (A7), U8.21 (IO), U9.3 (A14), U11.4 (A7)
/GA8: U3.27 (A8), U5.36 (A8), U8.22 (IO), U9.27 (A8), U11.29 (A8)
/GA9: U3.26 (A9), U5.37 (A9), U8.23 (IO), U9.26 (A9), U11.28 (A9)
/GA10: U3.23 (A10), U5.38 (A10), U8.25 (IO), U9.23 (A10), U11.24 (A10)
/GA11: U3.25 (A11), U5.40 (A11), U8.31 (IO), U9.25 (A11), U11.27 (A11)
/GA12: U3.4 (A12), U5.41 (A12), U8.32 (IO), U9.4 (A12), U11.3 (A12)
/GA13: U3.5 (A7), U5.42 (A13), U8.34 (IO), U9.5 (A7), U11.30 (A13)
/GA14: U3.28 (A13), U5.43 (A14), U8.35 (IO), U9.28 (A13), U11.31 (A14)
/GA15: U5.44 (A15), U8.36 (IO)
/GCLK: U8.43 (IO), U23.2
/GCLK_BUF: U5.1 (~CLK), U23.4
/GD0: U3.17 (D3), U5.9 (D0), U8.45 (IO), U9.17 (D3), U11.13 (O0)
/GD1: U3.15 (D2), U5.10 (D1), U8.46 (IO), U9.15 (D2), U11.14 (O1)
/GD2: U3.18 (D4), U5.7 (D2), U8.40 (IO), U9.18 (D4), U11.15 (O2)
/GD3: U3.14 (D1), U5.3 (D3), U8.37 (IO), U9.14 (D1), U11.18 (O3)
/GD4: U3.19 (D5), U5.2 (D4), U8.42 (IO), U9.19 (D5), U11.19 (O4)
/GD5: U3.13 (D0), U5.4 (D5), U8.38 (IO), U9.13 (D0), U11.20 (O5)
/GD6: U3.20 (D6), U5.5 (D6), U8.39 (IO), U9.20 (D6), U11.21 (O6)
/GD7: U3.21 (D7), U5.8 (D7), U8.41 (IO), U9.21 (D7), U11.22 (O7)
/GMA15: U3.31 (A15), U8.48 (IO), U9.31 (A15), U11.2 (A15)
/GMA16: U3.2 (A16), U8.6 (IO), U9.2 (A16)
/GMA17: U3.1 (A18), U8.5 (IO), U9.1 (A18)
/GMA18: U3.30 (A17), U8.7 (IO), U9.30 (A17)
/IN_L: J3.4, R1.2, R7.1
/IN_R: J3.1, R19.1, R34.2
/MIDI_CLK: U8.97 (IO), U13.39 (X1)
/MIDI_IN: U4.14 (IOA2), U13.16 (MIDI_IN)
/MIDI_L: C1.1, U13.1 (AOUTL)
/MIDI_R: C21.1, U13.2 (AOUTR)
/SAA_CLK: U8.96 (IO), U20.8 (CLK)
/SAA_L: C2.1, C45.1, R48.2
/SAA_R: C19.1, C46.1, R49.2
/SND_L: C83.2, J1.T, J1.TN, J2.4, R60.2, R62.2
/SND_R: C82.2, J1.R, J1.RN, J2.1, R60.1, R61.2
/TCK: J5.1, R59.1, U8.89 (TCK)
/TDI: J5.9, R52.1, U8.4 (TDI)
/TDO: J5.3, U8.104 (TDO)
/TMS: J5.5, R53.1, U8.20 (TMS)
/YM_M: U4.38 (M), U8.69 (IO), U10.38 (M)
/~ARD: U4.36 (~RD), U8.75 (IO), U10.36 (~RD)
/~AWR: U4.35 (~WR), U8.78 (IO), U10.35 (~WR), U20.1 (~WR)
/~DOS: J4.a4, R41.2, U8.108 (IO)
/~GINT: U5.12 (~INT), U8.44 (IO)
/~GIORQ: U5.16 (~IORQ), U8.29 (IO)
/~GM1: U5.24 (~M1), U8.9 (IO)
/~GMREQ: U5.15 (~MREQ), U8.30 (IO)
/~GRAM1: U3.22 (~CE), U8.8 (IO)
/~GRAM2: U8.2 (IO), U9.22 (~CE)
/~GRD: U3.24 (~OE), U5.18 (~RD), U8.28 (IO), U9.24 (~OE), U11.25 (~OE/VPP)
/~GROM: U8.47 (IO), U11.23 (~CE)
/~GRST: U5.23 (~RESET), U8.10 (IO)
/~GWR: U3.29 (~WE), U5.19 (~WR), U8.27 (IO), U9.29 (~WE)
/~IODOS: J4.b20, R38.2, U8.131 (IO)
/~IORQGE: U8.119 (IO), U21.1
/~IORQ: J4.b17, U8.121 (IO)
/~M1: J4.b24, U8.137 (IO)
/~MREQ: J4.b16, U8.120 (IO)
/~RD: J4.b18, R42.2, U8.122 (IO)
/~RSTOUT: U4.24 (~IC), U8.81 (IO), U10.24 (~IC), U13.38 (~RST/~PD)
/~RST: J4.a20, U8.127 (IN/GCLRn)
/~SAA_CS: U8.93 (IO), U20.2 (~CS)
/~WAIT: J4.b21, U8.132 (IO)
/~WR: J4.b19, U8.126 (IN/OE1)
/~YM1_CS: U4.34 (~CS), U8.79 (IO)
/~YM2_CS: U8.80 (IO), U10.34 (~CS)
GND: C4.1, C13.2, C14.2, C15.2, C20.2, C22.2, C23.2, C24.2, C25.2, C26.2, C27.2, C28.2, C29.2, C30.2, C31.2, C32.2, C33.2, C34.2, C35.2, C36.2, C37.2, C38.2, C39.2, C40.2, C41.2, C42.2, C43.2, C44.2, C45.2, C46.2, C47.2, C48.2, C49.2, C50.2, C51.2, C52.2, C53.2, C54.2, C55.2, C56.2, C57.2, C58.2, C59.2, C60.1, C61.1, C62.1, C63.1, C64.1, C65.1, C66.1, C67.1, C68.1, C69.1, C70.1, C71.1, C72.1, C73.1, C74.1, C75.2, C76.2, C77.2, C78.2, C79.2, C80.2, C81.2, C84.1, C85.1, J1.S, J2.2, J2.3, J3.2, J3.3, J4.a6, J4.a7, J4.a14, J4.a30, J4.b30, J5.2, J5.10, R7.2, R8.1, R9.1, R10.1, R11.2, R19.2, R35.1, R36.1, R37.1, R59.2, R61.1, R62.1, SW1.6, SW1.7, SW1.8, SW1.9, SW1.10, U1.4 (V-), U2.4 (V-), U3.16 (GND), U4.1 (GND), U4.17 (AGND), U5.26 (GND), U6.6 (Vss), U7.4 (V-), U8.3 (GNDIO), U8.13 (GNDIO), U8.17 (GNDIO), U8.26 (GNDIO), U8.33 (GNDIO), U8.52 (GNDINT), U8.57 (GNDINT), U8.59 (GNDIO), U8.64 (GNDIO), U8.77 (GNDIO), U8.85 (GNDIO), U8.94 (GNDIO), U8.105 (GNDIO), U8.114 (GNDIO), U8.124 (GNDINT), U8.129 (GNDINT), U8.135 (GNDIO), U9.16 (GND), U10.1 (GND), U10.17 (AGND), U11.16 (GND), U12.6 (Vss), U13.4 (AGND), U13.7 (MICIN), U13.9 (GND), U13.10 (A0), U13.13 (GND), U13.14 (~CS), U13.15 (~RD), U13.18 (GND), U13.25 (GND), U13.36 (GND), U13.45 (GND), U13.48 (GND), U13.49 (GND), U14.3 (A1), U14.5 (A3), U14.7 (A5), U14.9 (A7), U14.10 (GND), U14.19 (CE), U15.1 (GND), U16.2 (GND), U17.2 (GND), U18.2 (GND), U19.1 (GND), U20.9 (GND), U21.3 (GND), U23.1, U23.3 (GND), X1.2 (GND), X2.2 (GND)
unnamed: C1.2, R2.2
unnamed: C2.2, R4.2
unnamed: C3.2, R6.2
unnamed: C5.2, R12.2
unnamed: C6.2, R13.2
unnamed: C7.2, R14.2
unnamed: C8.2, R16.2, R27.2
unnamed: C9.2, R17.2, R26.2
unnamed: C10.2, R18.2, R24.2
unnamed: C11.2, R20.2, R21.2
unnamed: C12.2, R28.2
unnamed: C16.2, R29.2
unnamed: C17.2, R30.2
unnamed: C18.2, R31.2
unnamed: C19.2, R32.2
unnamed: C21.2, R33.2
unnamed: C82.1, R15.2, U1.1
unnamed: C83.1, R25.2, U1.7
unnamed: J4.a13, U21.4
unnamed: TP1.1, U8.72 (IO)
unnamed: TP2.1, U8.71 (IO)
unnamed: TP3.1, U8.68 (IO)
unnamed: TP4.1, U8.67 (IO)
unnamed: TP5.1, U8.143 (IO)
unnamed: TP6.1, U8.1 (IO)
unnamed: C4.2, R5.1, R11.1, U1.3 (+), U1.5 (+)
unnamed: R15.1, R21.1, R24.1, R26.1, R27.1, R28.1, R29.1, R30.1, R31.1, R32.1, R33.1, R34.1, U1.2 (-)
unnamed: R1.1, R2.1, R4.1, R6.1, R12.1, R13.1, R14.1, R16.1, R17.1, R18.1, R20.1, R25.1, U1.6 (-)
unnamed: C14.1, C15.1, U2.3 (+), U6.7 (Rb)
unnamed: R23.1, U2.1, U2.2 (-)
unnamed: C20.1, U2.5 (+), U6.2 (ToBUFF)
unnamed: R22.1, U4.23 (OP-O)
unnamed: U4.39 (S), U6.5 (CLOCK)
unnamed: U4.22 (SH), U6.3 (LOAD)
unnamed: C13.1, R23.2, U6.8 (Mp)
unnamed: R40.1, U7.1, U7.2 (-)
unnamed: R39.1, U10.23 (OP-O)
unnamed: U10.39 (S), U12.5 (CLOCK)
unnamed: U10.22 (SH), U12.3 (LOAD)
unnamed: C22.1, R40.2, U12.8 (Mp)
unnamed: C23.1, C24.1, U7.3 (+), U12.7 (Rb)
unnamed: C27.1, U7.5 (+), U12.2 (ToBUFF)
unnamed: C28.1, C29.1, U13.34 (OUTVC12)
unnamed: C25.1, C26.1, U13.5 (VCM)
unnamed: R43.2, U14.18 (B0)
unnamed: R44.2, U14.16 (B2)
unnamed: R45.2, U14.14 (B4)
unnamed: R50.2, U14.12 (B6)
unnamed: R51.1, U20.6 (Iref)
unnamed: C43.1, R46.1, R48.1, U20.4 (OutL)
unnamed: C44.1, R47.1, R49.1, U20.5 (OutR)

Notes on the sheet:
SAA1099
CONFIGURATION
open-drain
GENERAL SOUND
TURBO SOUND FM
MIXER
CPLD
JTAG
POWER
MIDI
CLOCK

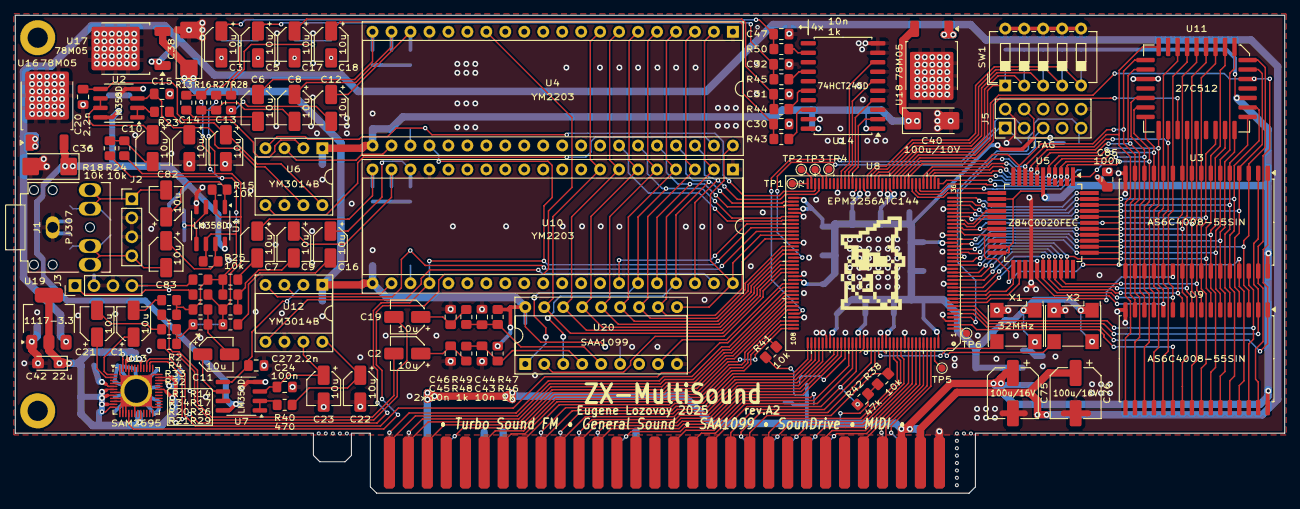
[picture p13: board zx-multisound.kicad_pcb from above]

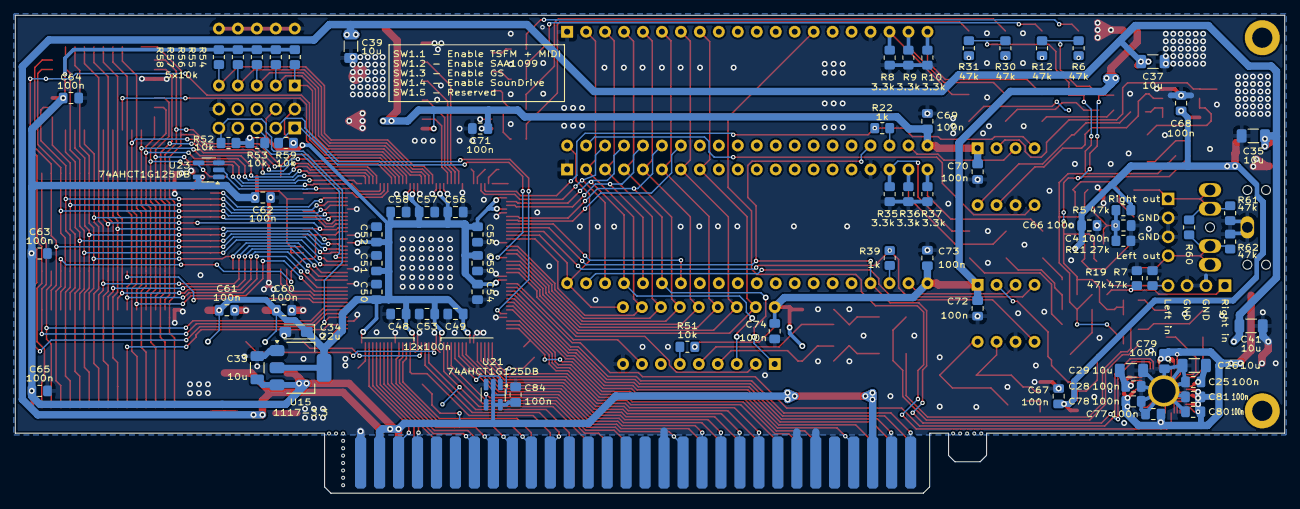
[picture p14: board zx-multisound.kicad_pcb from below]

Board: 2 copper layers, 170.0 x 64.0 mm, 185 parts (75 on the bottom side), 189 nets.

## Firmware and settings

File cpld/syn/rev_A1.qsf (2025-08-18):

# -------------------------------------------------------------------------- #
#
# Copyright (C) 1991-2013 Altera Corporation
# Your use of Altera Corporation's design tools, logic functions 
# and other software and tools, and its AMPP partner logic 
# functions, and any output files from any of the foregoing 
# (including device programming or simulation files), and any 
# associated documentation or information are expressly subject 
# to the terms and conditions of the Altera Program License 
# Subscription Agreement, Altera MegaCore Function License 
# Agreement, or other applicable license agreement, including, 
# without limitation, that your use is for the sole purpose of 
# programming logic devices manufactured by Altera and sold by 
# Altera or its authorized distributors.  Please refer to the 
# applicable agreement for further details.
#
# -------------------------------------------------------------------------- #
#
# Quartus II 64-Bit
# Version 13.0.1 Build 232 06/12/2013 Service Pack 1 SJ Full Version
# Date created = 12:04:27  October 04, 2020
#
# -------------------------------------------------------------------------- #
#
# Notes:
#
# 1) The default values for assignments are stored in the file:
#		zx_multisound_assignment_defaults.qdf
#    If this file doesn't exist, see file:
#		assignment_defaults.qdf
#
# 2) Altera recommends that you do not modify this file. This
#    file is updated automatically by the Quartus II software
#    and any changes you make may be lost or overwritten.
#
# -------------------------------------------------------------------------- #


set_global_assignment -name FAMILY MAX3000A
set_global_assignment -name DEVICE "EPM3256ATC144-10"
set_global_assignment -name TOP_LEVEL_ENTITY zx_multisound
set_global_assignment -name ORIGINAL_QUARTUS_VERSION "13.0 SP1"
set_global_assignment -name PROJECT_CREATION_TIME_DATE "12:04:27  OCTOBER 04, 2020"
set_global_assignment -name LAST_QUARTUS_VERSION "13.0 SP1"
set_global_assignment -name PROJECT_OUTPUT_DIRECTORY output
set_global_assignment -name DEVICE_FILTER_PIN_COUNT 144
set_global_assignment -name ERROR_CHECK_FREQUENCY_DIVISOR "-1"
set_global_assignment -name SDC_FILE clocks.sdc
set_global_assignment -name VERILOG_FILE ../rtl/top.v
set_global_assignment -name VHDL_INPUT_VERSION VHDL_2008
set_global_assignment -name VHDL_SHOW_LMF_MAPPING_MESSAGES OFF
set_global_assignment -name VERILOG_INPUT_VERSION SYSTEMVERILOG_2005
set_global_assignment -name VERILOG_SHOW_LMF_MAPPING_MESSAGES OFF
set_global_assignment -name MAX7000_DEVICE_IO_STANDARD "3.3-V LVTTL"
set_global_assignment -name SAVE_DISK_SPACE OFF
set_global_assignment -name TIMEQUEST_MULTICORNER_ANALYSIS OFF
set_global_assignment -name SYNTH_TIMING_DRIVEN_SYNTHESIS OFF
set_location_assignment PIN_1 -to gram4_n
set_location_assignment PIN_2 -to gram2_n
set_location_assignment PIN_5 -to gma[17]
set_location_assignment PIN_6 -to gma[16]
set_location_assignment PIN_7 -to gma[18]
set_location_assignment PIN_8 -to gram1_n
set_location_assignment PIN_9 -to gm1_n
set_location_assignment PIN_10 -to grst_n
set_location_assignment PIN_11 -to ga[0]
set_location_assignment PIN_12 -to ga[1]
set_location_assignment PIN_14 -to ga[2]
set_location_assignment PIN_15 -to ga[3]
set_location_assignment PIN_16 -to ga[4]
set_location_assignment PIN_18 -to ga[5]
set_location_assignment PIN_19 -to ga[6]
set_location_assignment PIN_21 -to ga[7]
set_location_assignment PIN_22 -to ga[8]
set_location_assignment PIN_23 -to ga[9]
set_location_assignment PIN_25 -to ga[10]
set_location_assignment PIN_27 -to gwr_n
set_location_assignment PIN_28 -to grd_n
set_location_assignment PIN_29 -to giorq_n
set_location_assignment PIN_30 -to gmreq_n
set_location_assignment PIN_31 -to ga[11]
set_location_assignment PIN_32 -to ga[12]
set_location_assignment PIN_34 -to ga[13]
set_location_assignment PIN_35 -to ga[14]
set_location_assignment PIN_36 -to ga[15]
set_location_assignment PIN_37 -to gd[3]
set_location_assignment PIN_38 -to gd[5]
set_location_assignment PIN_39 -to gd[6]
set_location_assignment PIN_40 -to gd[2]
set_location_assignment PIN_41 -to gd[7]
set_location_assignment PIN_42 -to gd[4]
set_location_assignment PIN_43 -to gclk
set_location_assignment PIN_44 -to gint_n
set_location_assignment PIN_45 -to gd[0]
set_location_assignment PIN_46 -to gd[1]
set_location_assignment PIN_47 -to grom_n
set_location_assignment PIN_48 -to gma[15]
set_location_assignment PIN_49 -to cfg[0]
set_location_assignment PIN_53 -to cfg[1]
set_location_assignment PIN_54 -to cfg[2]
set_location_assignment PIN_55 -to cfg[3]
set_location_assignment PIN_56 -to cfg[4]
set_location_assignment PIN_60 -to dac3_out
set_location_assignment PIN_61 -to dac2_out
set_location_assignment PIN_62 -to dac1_out
set_location_assignment PIN_63 -to dac0_out
set_location_assignment PIN_69 -to ym_m
set_location_assignment PIN_70 -to fm1_ena
set_location_assignment PIN_74 -to aa0
set_location_assignment PIN_75 -to ard_n
set_location_assignment PIN_78 -to awr_n
set_location_assignment PIN_79 -to ym1_cs_n
set_location_assignment PIN_80 -to ym2_cs_n
set_location_assignment PIN_81 -to rstout_n
set_location_assignment PIN_82 -to fm2_ena
set_location_assignment PIN_83 -to ad[0]
set_location_assignment PIN_84 -to ad[1]
set_location_assignment PIN_86 -to ad[2]
set_location_assignment PIN_87 -to ad[3]
set_location_assignment PIN_88 -to ad[4]
set_location_assignment PIN_90 -to ad[5]
set_location_assignment PIN_91 -to ad[6]
set_location_assignment PIN_92 -to ad[7]
set_location_assignment PIN_93 -to saa_cs_n
set_location_assignment PIN_96 -to saa_clk
set_location_assignment PIN_97 -to midi_clk
set_location_assignment PIN_98 -to zxa[14]
set_location_assignment PIN_99 -to zxa[15]
set_location_assignment PIN_100 -to zxa[12]
set_location_assignment PIN_101 -to zxa[13]
set_location_assignment PIN_102 -to zxd[7]
set_location_assignment PIN_103 -to zxd[0]
set_location_assignment PIN_106 -to zxd[1]
set_location_assignment PIN_107 -to zxd[2]
set_location_assignment PIN_108 -to zxdos_n
set_location_assignment PIN_109 -to zxa[0]
set_location_assignment PIN_110 -to zxd[6]
set_location_assignment PIN_111 -to zxa[1]
set_location_assignment PIN_112 -to zxd[5]
set_location_assignment PIN_113 -to zxa[2]
set_location_assignment PIN_116 -to zxd[3]
set_location_assignment PIN_117 -to zxa[3]
set_location_assignment PIN_118 -to zxd[4]
set_location_assignment PIN_119 -to zxiorqge_n
set_location_assignment PIN_120 -to zxmreq_n
set_location_assignment PIN_121 -to zxiorq_n
set_location_assignment PIN_122 -to zxrd_n
set_location_assignment PIN_125 -to clkx
set_location_assignment PIN_126 -to zxwr_n
set_location_assignment PIN_127 -to rst_n
set_location_assignment PIN_128 -to clk32
set_location_assignment PIN_131 -to zxiodos_n
set_location_assignment PIN_132 -to zxwait_n
set_location_assignment PIN_133 -to zxa[7]
set_location_assignment PIN_134 -to zxa[6]
set_location_assignment PIN_136 -to zxa[5]
set_location_assignment PIN_137 -to zxm1_n
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

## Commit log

2022-06-02 wip pcb rev.A
    [zx-supersound.kicad_pcb, zx-supersound.kicad_sch]
2022-11-10 update pcb rev.A - final version; add errata
    [zx-multisound.kicad_pcb, zx-multisound.kicad_sch]
2022-11-18 add pcb rev.A1
    [zx-multisound.kicad_pcb, zx-multisound.kicad_sch]
2023-09-09 update errata for pcb rev.A and rev.A1
2025-01-28 update pcb rev.A and rev.A1 errata
2025-03-29 add pcb rev.A2
    [zx-multisound.kicad_pcb, zx-multisound.kicad_sch]
